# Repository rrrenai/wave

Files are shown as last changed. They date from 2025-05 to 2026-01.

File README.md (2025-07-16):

# ~ wave ~
*wave* is an attempt to revolutionize the head phone listening experience. If you know me irl, you'll know that I easily lose focus when people talk to me and I proactively believe I am going deaf. *wave* attempts to fix this issue by serving a a directional source selector for incoming sounds, eliminating distractions from environmental noise. 

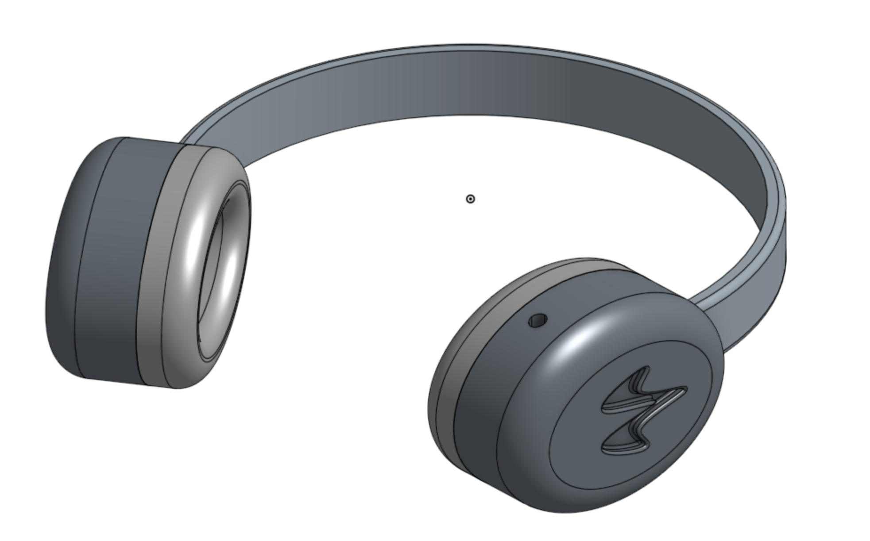
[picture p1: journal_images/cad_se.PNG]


These headphones utilize an FPGA, I2S MEMS microphones, and scrap headphone drivers. The FPGA and RPI work in tandem to collect and process incoming signals real time, seamlessly upgrading the listening experience.

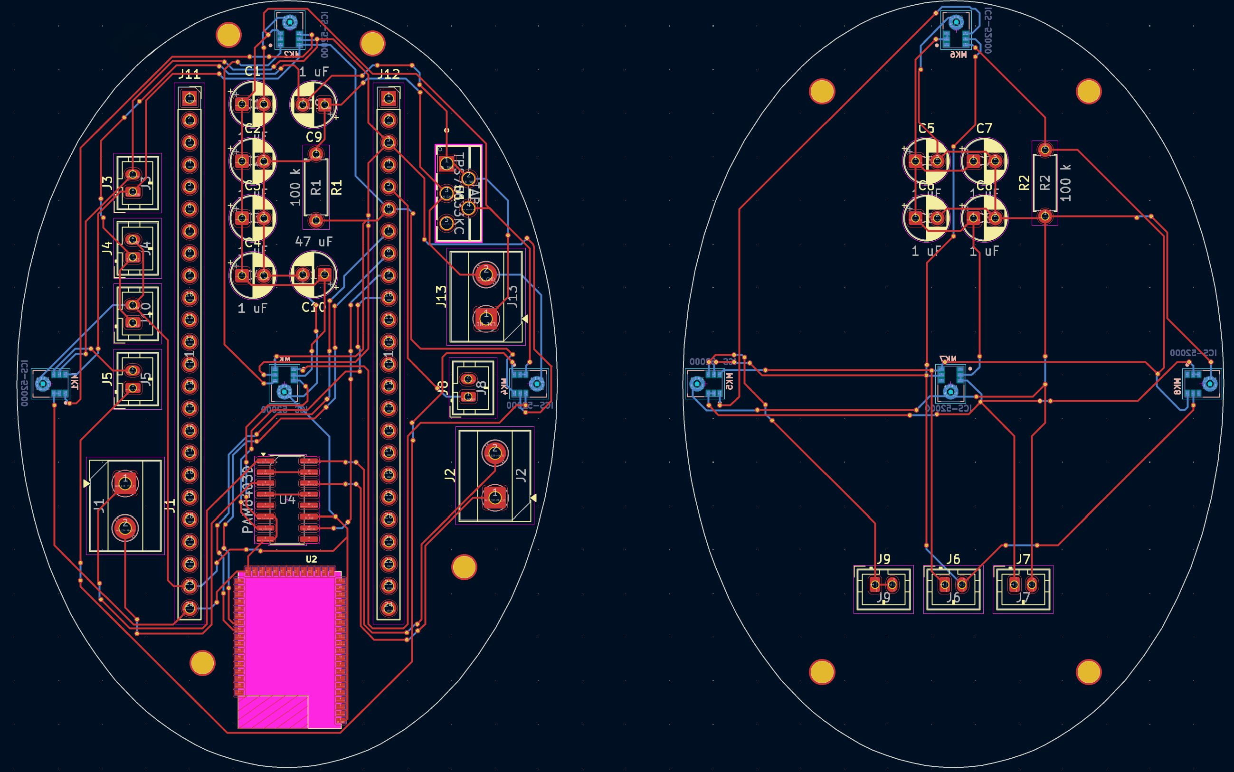
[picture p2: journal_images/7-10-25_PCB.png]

The headphones have 2 half PCBs, which are connected via 3 JST cables. It collects audio data through 8 ICS-520000 MEMS microphones, connected together via TDM and parsed directly on the FPGA. The data is then quickly ran through a reduced TF-Gridnet DNN, where the target speaker is isolated and played back to the user.

# Schematic
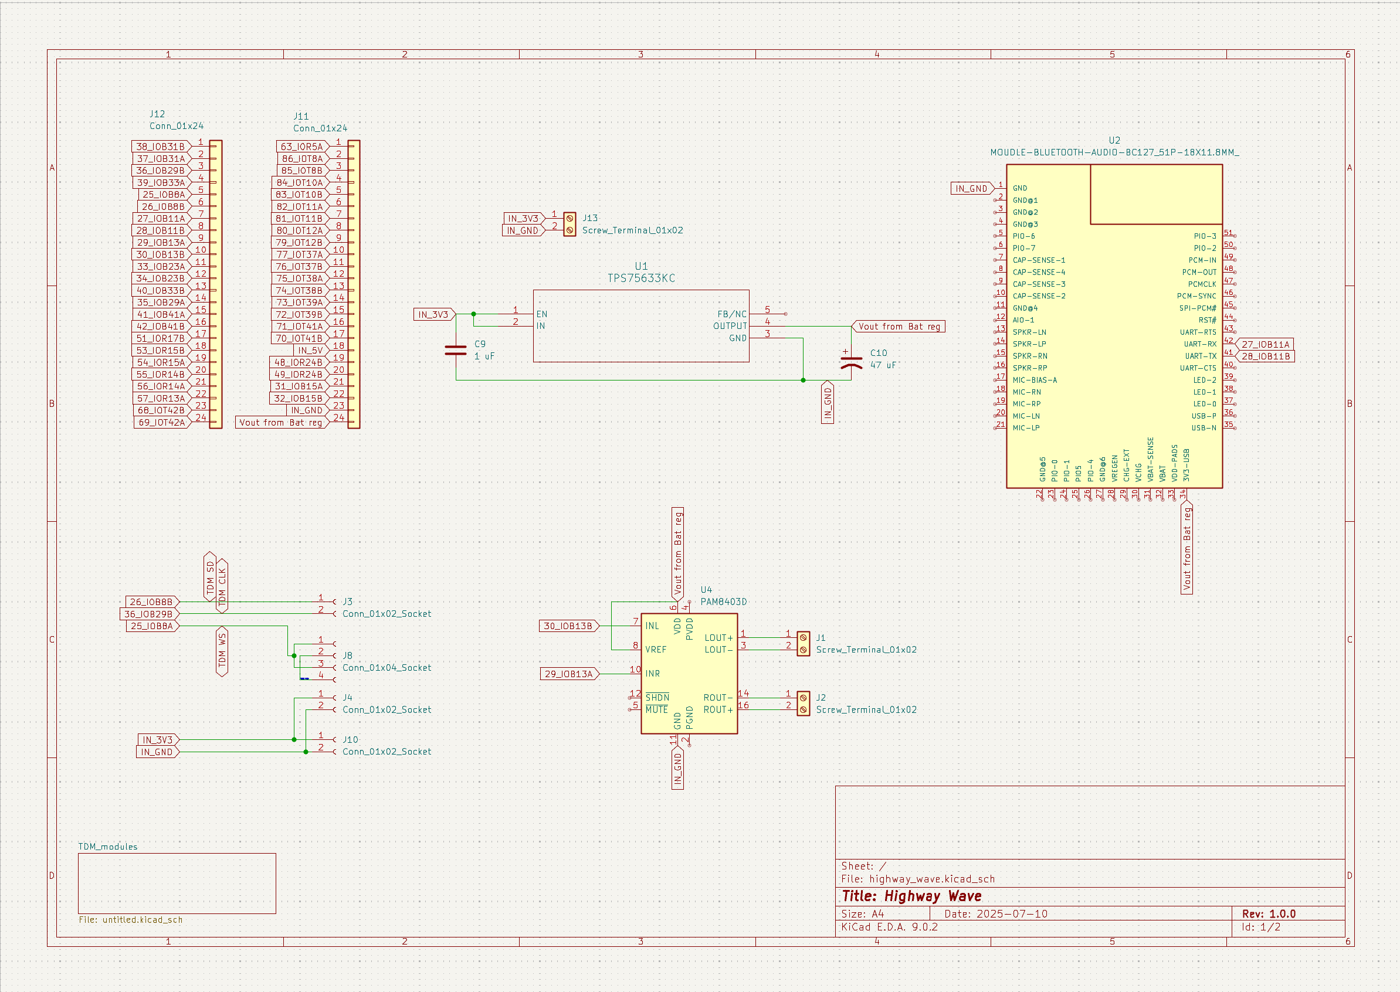
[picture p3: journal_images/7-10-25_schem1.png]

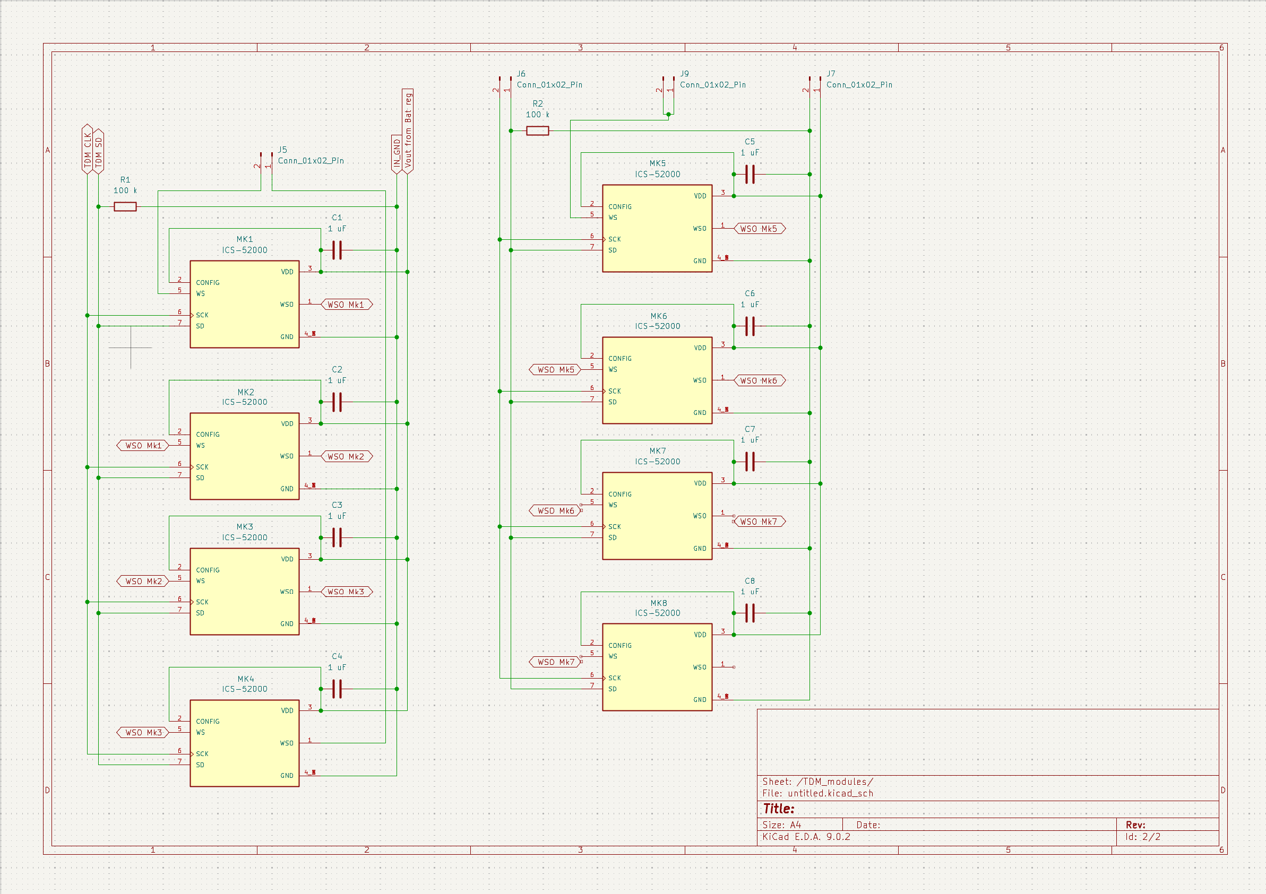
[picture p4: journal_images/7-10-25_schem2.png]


# BOM
| Item | Price | Quantity |  Subtotal |
|---|---|---|---|
| Ear cup / case |  $ 10.00 | 1 |  $ 10.00 |
| Head band |  $ 10.00 | 1 |  $ 10.00 |
| Bluetooth |  $ 1.79  | 1 |  $ 1.79 |
| Aliexpress shipping |  $ 6.63 | 1 |  $ 6.63 |
| Aliexpress tax |  $ 4.42 | 1 |  $ 4.42 |
| Cushion / seal material |  $ 5.26 | 2 |  $ 10.52 |
| LiPo |  $ 4.95 | 2 |  $ 9.90 |
| Sound amp |  $ 1.26 | 1 |  $ 1.26 |
| Charge Protection IC |  $ 1.99 | 1 |  $ 1.99 |
| Tang Nano 9k |  $ 18.17 | 1 |  $ 18.17 |
| Amazon Shipping / Handling  |  $ 12.98 | 1 |  $ 12.98 |
| Amazon Estimated Tax |  $ 9.11 | 1 |  $ 9.11 |
| Audio driver for headphones |  $ 10.69 | 2 |  $ 21.38 |
| Digikey Shipping |  $ 6.99 | 1 |  $ 6.99 |
| Digikey Tarriff |  $ 2.14 | 1 |  $ 2.14 |
| Ebay shipping |  $ 4.95 | 1 |  $ 4.95 |
| Ebay tax |  $ 0.64 | 1 |  $ 0.64 |
| Buttons |  $ 5.00  | 4 |  $ 20.00 |
| LED |  $ - | 2 |  $ - |
| PCB (L + R) |  $ 8.27 | 1 |  $ 8.27 |
| I2S Microphones |  $ 2.84 | 10 |  $ 28.40 |
| Mouser shipping |  $ 7.99 | 1 |  $ 7.99 |
| TOTAL | | |  $ 197.53 |

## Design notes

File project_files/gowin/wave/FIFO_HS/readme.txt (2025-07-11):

_______________________________________________________________________________
       	  FIFO_HS阅读指南
----------------------------------------------------------------------
工程描述：FIFO HS IP设计，并加载物理约束、时序约束、GAO配置等，实现整个设计流程。
----------------------------------------------------------------------
目标器件：GW1N-9C，GW1N-LV9LQ144C6/I5
----------------------------------------------------------------------
文件列表
----------------------------------------------------------------------
.
| -- project
|    `-- readme.txt			        -->	自述文件
|    `-- FIFO_HS.gprj			    -->	参考设计工程
|    |-- impl
|    |-- src
|        |-- FIFO_HS
|        |   |-- FIFO_HS.ipc		-->	IP配置文件
|        |   |-- FIFO_HS.v			-->	IP文件
|        |   |-- FIFO_HS.vo			-->	仿真使用vo文件
|        |   |-- FIFO_HS_tmp.v		-->	例化模板文件
|        |-- rstn_gen.v			    -->	工程文件
|        |-- test_fifo.v			-->	工程顶层文件
|        |-- FIFO_HS.cst  	 		-->	工程物理约束文件
|        |-- FIFO_HS.gpa  	 		-->	工程GPA配置文件
|        |-- FIFO_HS.sdc  	 		-->	工程时序约束文件
|        |-- FIFO_HS.rao			-->	工程GAO配置文件
|        |-- FIFO_HS.gvio			-->	工程GVIO配置文件

_______________________________________________________________________________
       	 FIFO_HS  Readme
----------------------------------------------------------------------
Project description：FIFO HS IP design, with physical constraints, timing constraints, Gao configuration file, etc. to realize the whole design process.
----------------------------------------------------------------------
Object device: GW1N-9C, GW1N-LV9LQ144C6/I5
----------------------------------------------------------------------
File List:
----------------------------------------------------------------------
.
| -- project
|    `-- readme.txt						-->	Read Me file (this file)
|    `-- FIFO_HS.gprj					-->	Gowin Project File for Example Design
|    |-- impl
|    |-- src
|        |-- FIFO_HS
|        |   |-- FIFO_HS.ipc			-->	IP configuration file	
|        |   |-- FIFO_HS.v			    -->	IP file	
|        |   |-- FIFO_HS.vo			    -->	Verilog simulation File for tb
|        |   |-- FIFO_HS_tmp.v		    -->	Template file for instantiation
|        |-- rstn_gen.v			        -->	File for Gowin Project
|        |-- test_fifo.v			    -->	File for Gowin Project
|        |-- FIFO_HS.cst  	 		    -->	CST File
|        |-- FIFO_HS.gpa  	 		    -->	GPA File
|        |-- FIFO_HS.sdc  	 		    -->	SDC File
|        |-- FIFO_HS.rao			    -->	GAO File
|        |-- FIFO_HS.gvio			    -->	GVIO File

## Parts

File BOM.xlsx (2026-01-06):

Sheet: Final
Item | Received | Purpose | Part Name | Supplier | Source | Alternative | Price | Quantity | Subtotal
Ear cup / case |  | Comfort | Printing on print Legion + shipping cost | #print-legion |  |  | $10.00 |  | $0.00
Head band |  | Comfort |  | #print-legion |  |  | $10.00 |  | $0.00
Bluetooth |  |  | Bluetooth 5.0 Audio Receiver | Aliexpress | https://www.aliexpress.us/item/3256805886601588.html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 |  | $1.79 | 1 | $1.79
Aliexpress shipping |  |  |  | Aliexpress |  |  | $6.63 | 1 | $6.63
Aliexpress tax |  |  |  | Aliexpress |  |  | $4.42 | 1 | $4.42
Cushion / seal material | 2025-08-16 | Comfort |  | Aliexpress | https://www.aliexpress.us/item/3256806614332934.html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 |  | $5.26 | 2 | $10.52
LiPo | 2025-08-28 |  | LP603449 | Aliexpress | https://www.aliexpress.us/item/3256808031709894.html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 |  | $4.95 | 2 | $9.90
Sound amp | 2025-08-16 | Boost sound / bass | PAM8403 | Aliexpress | https://www.aliexpress.us/item/3256807092800375.html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 |  | $1.26 | 1 | $1.26
Charge Protection IC | 2025-08-16 |  | TP4056 or TPS75633 | Aliexpress | https://www.aliexpress.us/item/3256803400457978.html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 |  | $1.99 | 1 | $1.99
Tang Nano 9k | 2025-08-16 | Process mics | GOWIN GW1NR-9 RISC-V | Amazon | https://www.aliexpress.us/item/3256804387309562.html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 |  | $18.17 | 1 | $18.17
Amazon Shipping / Handling |  |  |  | Amazon |  |  | $12.98 |  | $0.00
Amazon Estimated Tax |  |  |  | Amazon |  |  | $9.11 |  | $0.00
Audio driver for headphones |  | Play audio | HPD-50N25PR00-32 | Digikey | https://www.digikey.com/en/products/detail/peerless-by-tymphany/HPD-50N25PR00-32/6211129 | https://www.amazon.com/dp/B0B3S2CYZS?ref_=cm_sw_r_cp_ud_dp_47YHT647GW0YA5WC0RF3_1 | $10.69 | 2 | $21.38
Digikey Shipping |  |  |  | Digikey |  |  | $6.99 | 1 | $6.99
Digikey Tarriff |  |  |  | Digikey |  |  | $2.14 | 1 | $2.14
Ebay shipping |  |  |  | Ebay |  |  |  |  | $0.00
Ebay tax |  |  |  | Ebay |  |  | $0.64 | 1 | $0.64
Buttons |  | volume & bluetooth |  | Have |  |  | $5.00 | 4 | $20.00
LED |  | power indicator |  | Have |  |  | $0.00 | 2 | $0.00
PCB (L + R) |  |  |  | JCLPCB |  |  | $8.27 | 1 | $8.27
I2S Microphones | 2025-08-03 | Take audio input | ICS-5200 | Mouser | https://www.mouser.com/ProductDetail/TDK-InvenSense/ICS-52000?qs=u4fy%2FsgLU9PL4sQfWE4e7w%3D%3D | https://www.digikey.ca/en/products/detail/tdk-invensense/ICS-52000/6221214 | $2.84 | 10 | $28.40
Mouser shipping |  |  |  | Mouser |  |  | $7.99 | 1 | $7.99
1x24 female header | 2025-08-16 |  |  | Aliexpress | https://www.aliexpress.com/item/2251832818063874.html?mp=1 |  | $1.74 | 1 | $1.74
JST socket | 2025-08-16 |  |  | Aliexpress | https://www.aliexpress.com/item/3256806836296359.html?mp=1 |  | $3.14 | 1 | $3.14
JST Housing |  |  |  | Aliexpress | https://www.aliexpress.com/item/3256804769340392.html?mp=1 |  | $1.37 | 1 | $1.37
ceramic caps | 2025-08-16 |  |  | Aliexpress | https://www.aliexpress.com/item/3256807448788129.html?mp=1 |  | $4.97 | 1 | $4.97
pam8403 | 2025-08-16 |  |  | Aliexpress | https://www.aliexpress.com/item/3256808555282957.html?mp=1 |  | $1.33 | 2 | $2.66
screw terminal | 2025-08-16 |  |  | Aliexpress | https://www.aliexpress.com/item/3256803442947487.html?mp=1 |  | $4.45 | 1 | $4.45
desoldering braid | 2025-08-16 |  |  | Aliexpress | https://www.aliexpress.com/item/3256805212208632.html?mp=1 |  | $1.26 | 1 | $1.26 |  | estimate | actual
Total Price |  |  |  |  |  |  |  |  | $170.08 | Aliexpress | $76.77 | $84.09
 |  |  |  |  |  |  |  |  |  | Digikey | $30.51 | $31.02
 |  |  |  |  |  |  |  |  |  | Mouser | $36.39 | $39.70
 |  |  |  |  |  |  |  |  |  | PCB? | $8.27 | $1.63
 |  |  |  |  |  |  |  |  |  | TOTAL | $151.94 | $156.44

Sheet: Breakdown
Item | Price per unit | Quantity | Subtotal
Bluetooth 5.0 Audio Receiver | $0.18 | 1 | $0.18
Cushion / seal material | $5.26 | 1 | $5.26
LP603449 | $4.95 | 1 | $4.95
PAM8403 | $1.26 | 1 | $1.26
TPS75633 | $0.40 | 1 | $0.40
GOWIN Tang Nano 9k | $18.17 | 1 | $18.17
HPD-50N25PR00-32 | $10.69 | 2 | $21.38
PCB (L + R) | $8.27 | 1 | $8.27
ICS-5200 | $2.84 | 8 | $22.72
1x24 female header | $0.17 | 2 | $0.35
JST socket | $0.03 | 20 | $0.63
JST Housing | $0.01 | 20 | $0.27
ceramic caps | $0.02 | 8 | $0.13
screw terminal | $0.45 | 3 | $1.33
TOTAL |  |  | $85.31

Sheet: Copy of Final
Item | Purpose | Part Name | Source | Alternative | Price | Quantity | Subtotal
Audio driver for headphones | Play audio | HPD-50N25PR00-32 | https://www.digikey.com/en/products/detail/peerless-by-tymphany/HPD-50N25PR00-32/6211129 | https://www.amazon.com/dp/B0B3S2CYZS?ref_=cm_sw_r_cp_ud_dp_47YHT647GW0YA5WC0RF3_1 | $10.69 | 2 | $21.38 | Total Price | $305.15
Sound amp | Boost sound / bass | PAM8403 | https://www.amazon.com/PAM8403-Stereo-Amplifier-Control-Potentiometer/dp/B07N1268RY |  | $5.69 | 1 | $5.69
Raspberry Pi Zero 2 WH | Run ML (quad core 64 processing) |  |  |  | $15.00 | 1 | $15.00
Tang Nano 9k | Process mics | GOWIN GW1NR-9 RISC-V | https://a.co/d/abLnqeb |  | $23.25 | 1 | $23.25
I2S Microphones | Take audio input | INMP441 | https://www.aliexpress.us/item/3256807347494500.html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 |  | $8.00 | 16 | $128.00
Ear cup / case | Comfort |  |  |  | $10.00 | 2 | $20.00
Cushion / seal material | Comfort |  |  |  | $10.00 | 2 | $20.00
Head band | Comfort |  |  |  | $10.00 | 1 | $10.00
Battery | power | Lithium Polymer ion Battery | https://a.co/d/7bSCAC6 |  | $10.00 | 1 | $10.00
Buttons | volume & bluetooth |  |  |  | $5.00 | 4 | $20.00
Bluetooth |  | BC127 |  |  | $6.05 | 1 | $6.05
Charge Protection IC |  | TP4056 or TPS75633 | https://www.ebay.com/itm/2-5-10PCS-TP4056-5V-1A-USB-18650-Lithium-Battery-Charger-Board-Protection-Module/132530522140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 |  | $2.16 | 1 | $2.16
LiPo |  | LP603449 | https://a.co/d/85SM4hH |  | $23.62 | 1 | $23.62
LED | power indicator

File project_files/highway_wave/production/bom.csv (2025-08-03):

Designator | Footprint | Quantity | Value | LCSC Part #
C5, C6, C7, C8 | C_Disc_D5.0mm_W2.5mm_P5.00mm | 4 | 1 uF
J10, J4, J6 | JST_PH_B2B-PH-K_1x02_P2.00mm_Vertical | 3 | Conn_01x02_Pin
J21 | TerminalBlock_MetzConnect_Type101_RT01602HBWC_1x02_P5.08mm_Horizontal | 1 | Screw_Terminal_01x02
J24 | JST_PH_B2B-PH-K_1x02_P2.00mm_Vertical | 1 | Conn_01x02_Socket
MK5, MK6, MK7, MK8 | MIC_ICS-52000 | 4 | ICS-52000
R2 | R_Axial_DIN0207_L6.3mm_D2.5mm_P7.62mm_Horizontal | 1 | 100 k

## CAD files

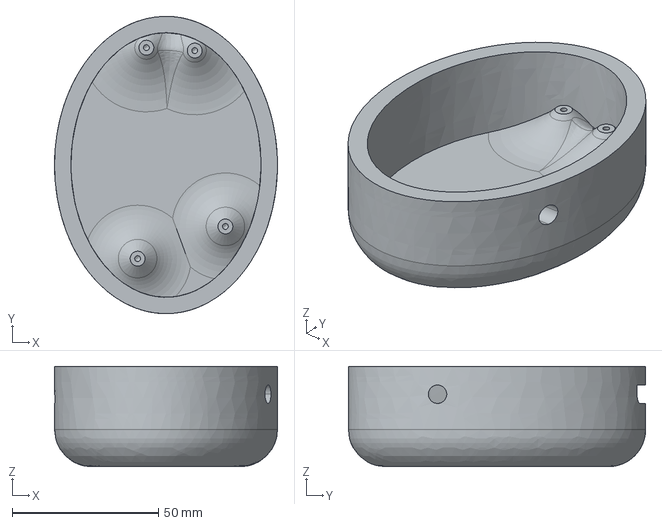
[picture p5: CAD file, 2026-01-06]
extra production/Ear_cup_L.step
76.2 x 101.6 x 34.3 mm

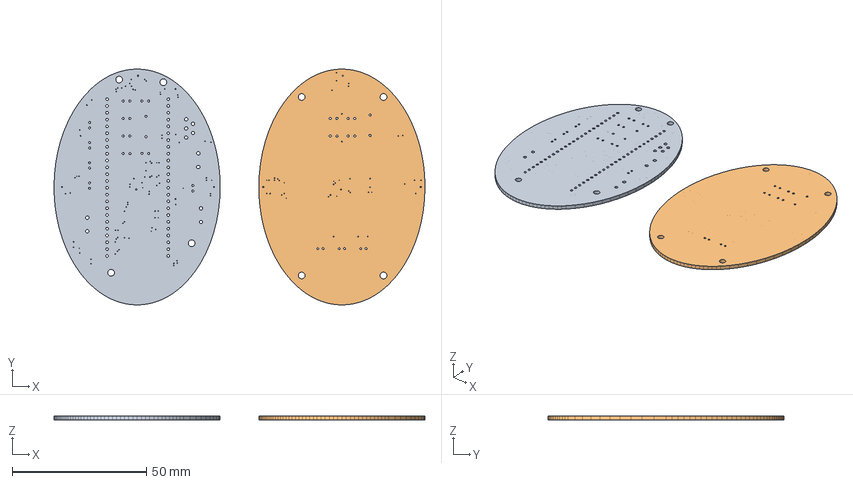
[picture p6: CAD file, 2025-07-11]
project_files/highway_wave/highway_wave.step
138.2 x 87.8 x 1.51 mm
highway_wave_PCB_1
highway_wave_PCB_2

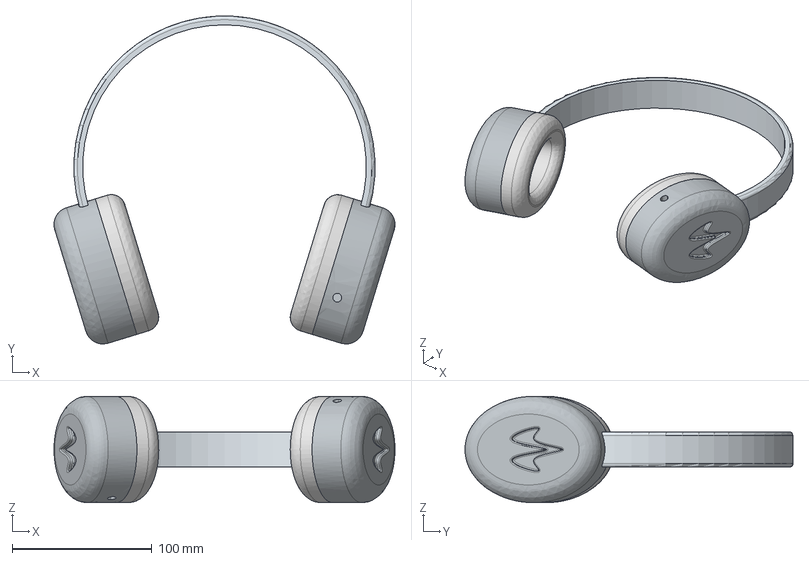
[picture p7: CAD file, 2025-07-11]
project_files/onshape/highway_wave.step
244.3 x 235.0 x 76.2 mm
Ear cup RIGHT
highway_wave_PCB_1
Ear pad x 2
Ear cup LEFT
head band
highway_wave_PCB_2

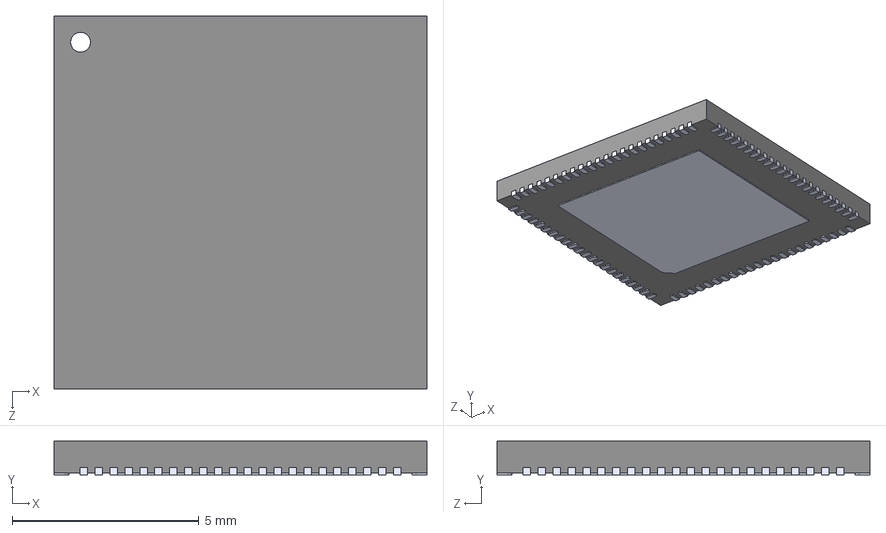
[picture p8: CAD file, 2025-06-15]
project_files/snapeda/GW1N-LV9QN88C6_I5_/GW1N-LV9QN88C6_I5_.step
10.0 x 0.9 x 10.0 mm

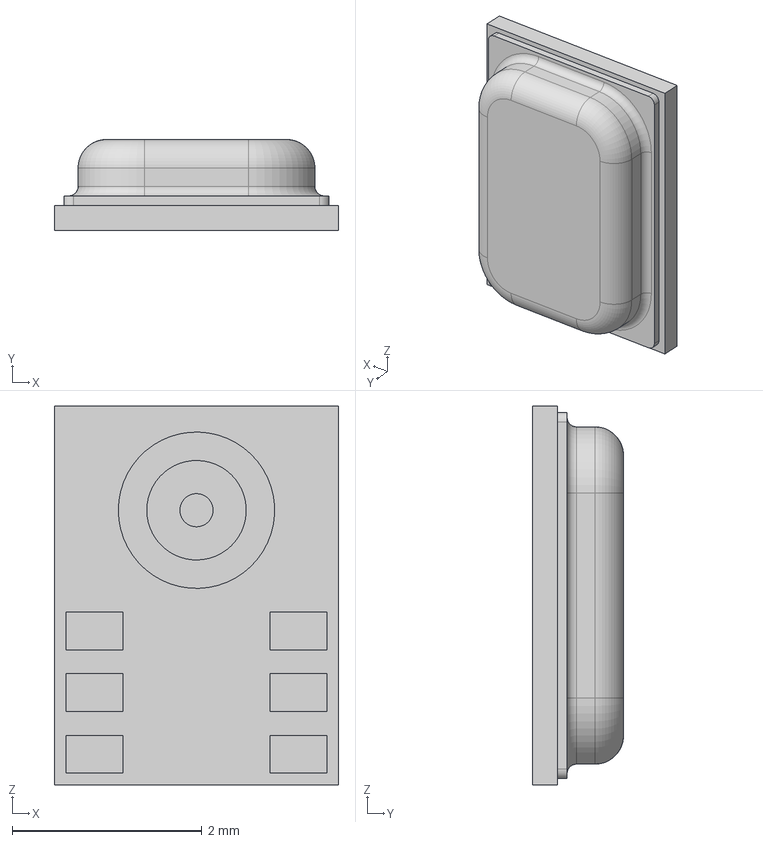
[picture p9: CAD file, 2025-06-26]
project_files/snapeda/ICS-43432/ICS-43432.step
3.00 x 0.961 x 4.00 mm

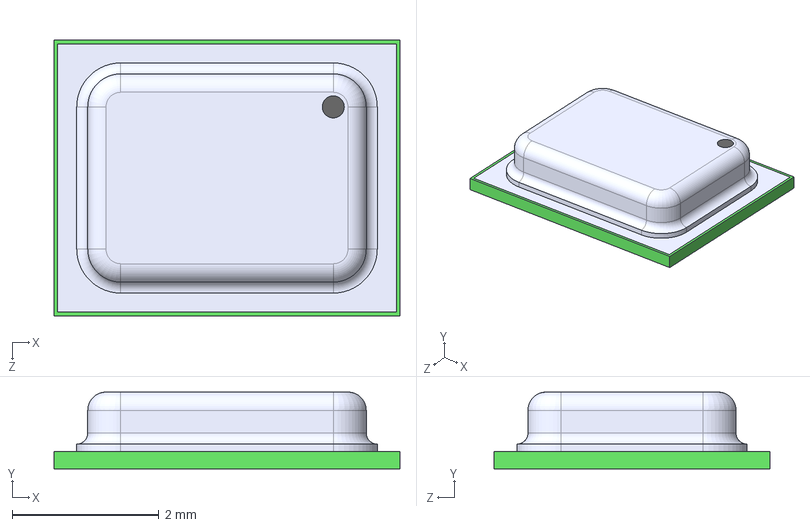
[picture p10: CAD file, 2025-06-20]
project_files/snapeda/INMP441ACEZ-R7/INMP441ACEZ-R7.step
4.72 x 1.05 x 3.76 mm

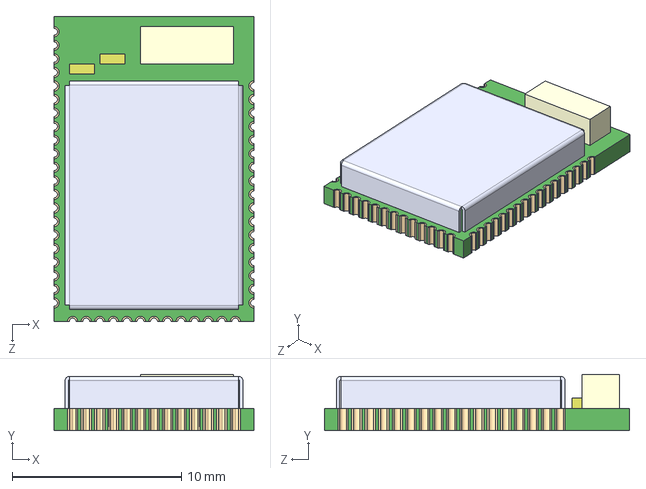
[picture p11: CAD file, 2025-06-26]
project_files/snapeda/MOUDLE-BLUETOOTH-AUDIO-BC127_51P-18X11.8MM_/MOUDLE-BLUETOOTH-AUDIO-BC127_51P-18X11.8MM_.step
11.8 x 3.32 x 18.0 mm

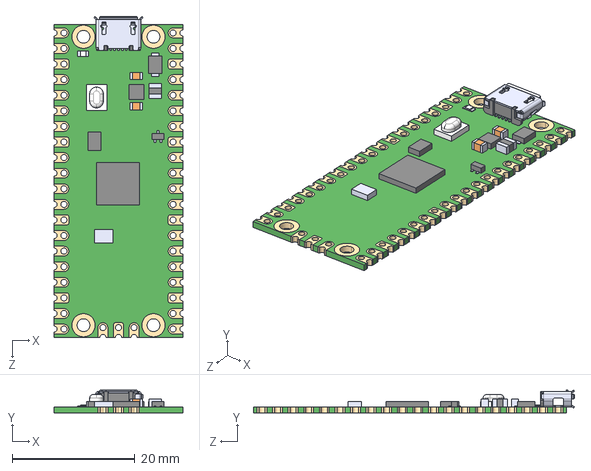
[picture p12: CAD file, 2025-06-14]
project_files/snapeda/RASPBERRY_PI_PICO/RASPBERRY_PI_PICO.step
21.0 x 3.73 x 52.3 mm

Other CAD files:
project_files/snapeda/ICS-52000/ICS-52000.step
extra production/Ear_cup_R.step

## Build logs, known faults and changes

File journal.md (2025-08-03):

---
title: "~ wave ~"
author: "rrrenai"
description: "Directional headphones to assist in multi-speaker selection"
created_at: "2024-05-22"
---
# Total time spent: 34.5
(Likely will increase after I get the parts cuz FPGAs are kind of a nightmare)

# May 22nd: Starting!

Hello, today I started writing my project pitch. I created my BOM and look at some other projects for inspiration.

Here's what I have so far:
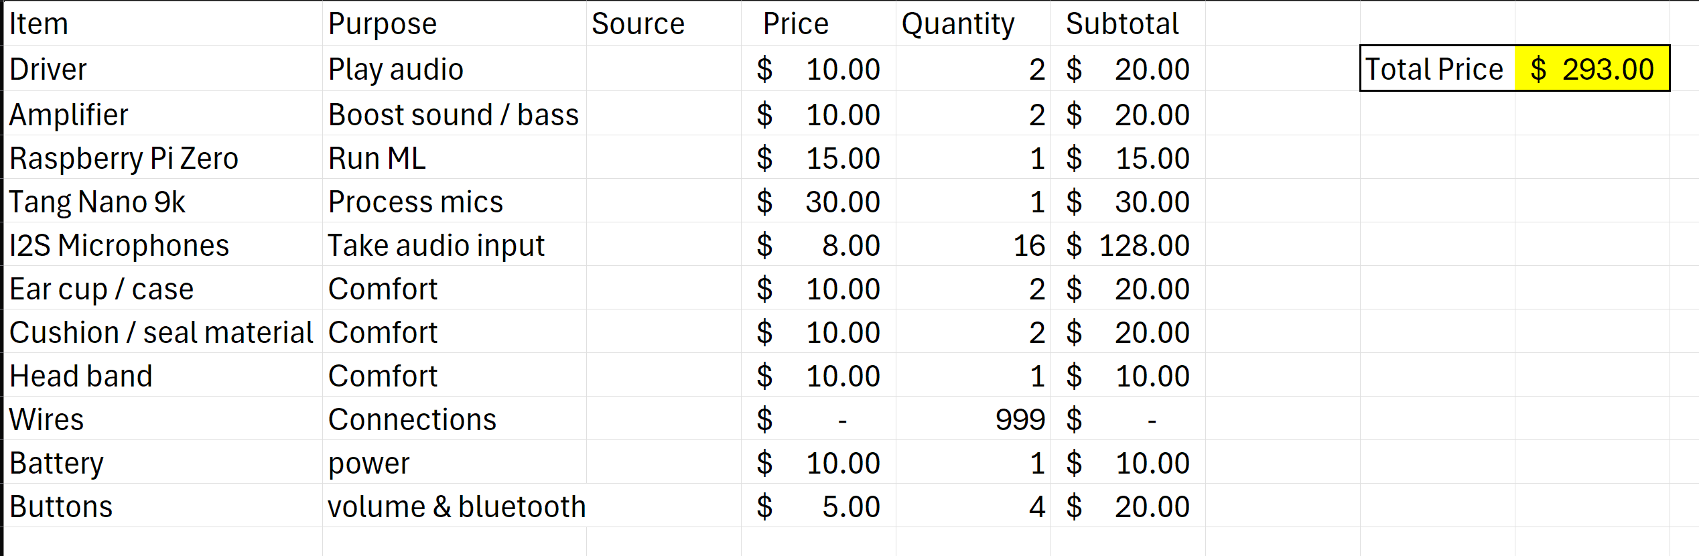
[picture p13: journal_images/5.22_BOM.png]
5/22/2025 BOM


I want to create something that can listen to omnidirectional audio and significantly clean up the output. I hope to help people with hearing problems.

**Time spent: 1 h**

---
# June 13th: Finished the headphone CAD

Today I used OnShape to design the electronic housing + headband.

The Tang Nano 9k is the largest item I anticipate using and thus I designed the ear cup around it. Here's a picture for the size of the Tang Nano 9k:
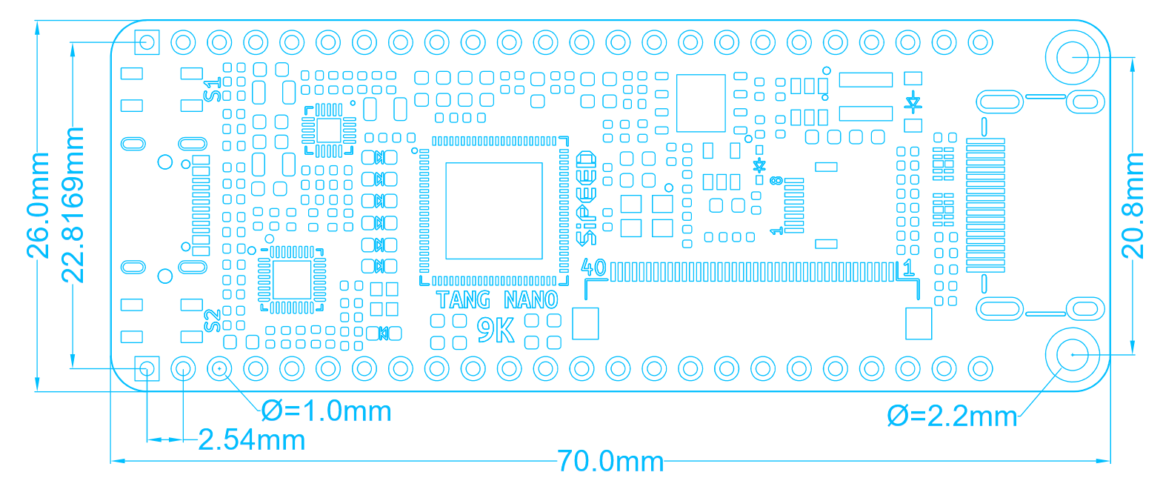
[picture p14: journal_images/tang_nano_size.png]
Tang Nano 9K


Here's what the headphones look like. I like the logo!
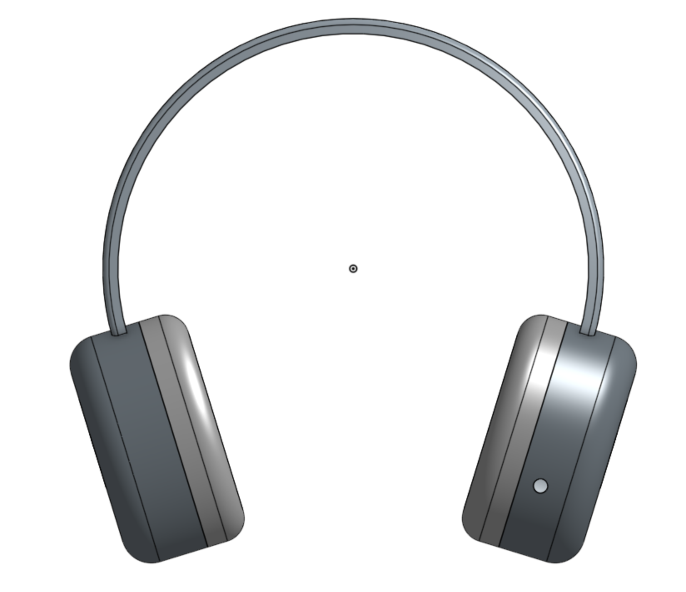
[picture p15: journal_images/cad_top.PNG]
top

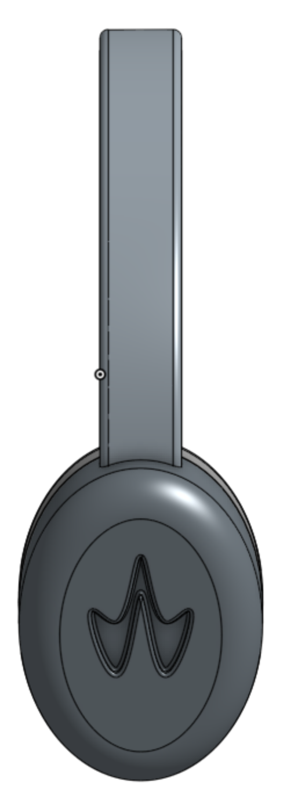
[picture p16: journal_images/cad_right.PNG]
side

southeast

Also, I started the schematic. I imported the Raspberry Pi Zero W onto the schematic and tried finding the footprint for the Tang Nano 9k but I wasn't able to :/ Guess I'll continue tmr? 

**Time spent: 4.5 h**

---
# June 14th: Continued working on Schem

There isn't any existing footprint for the Tang Nano 9k so I figured the Gowin chip it uses would be a sufficient representation of the board. Here's what the schem looks like so far::
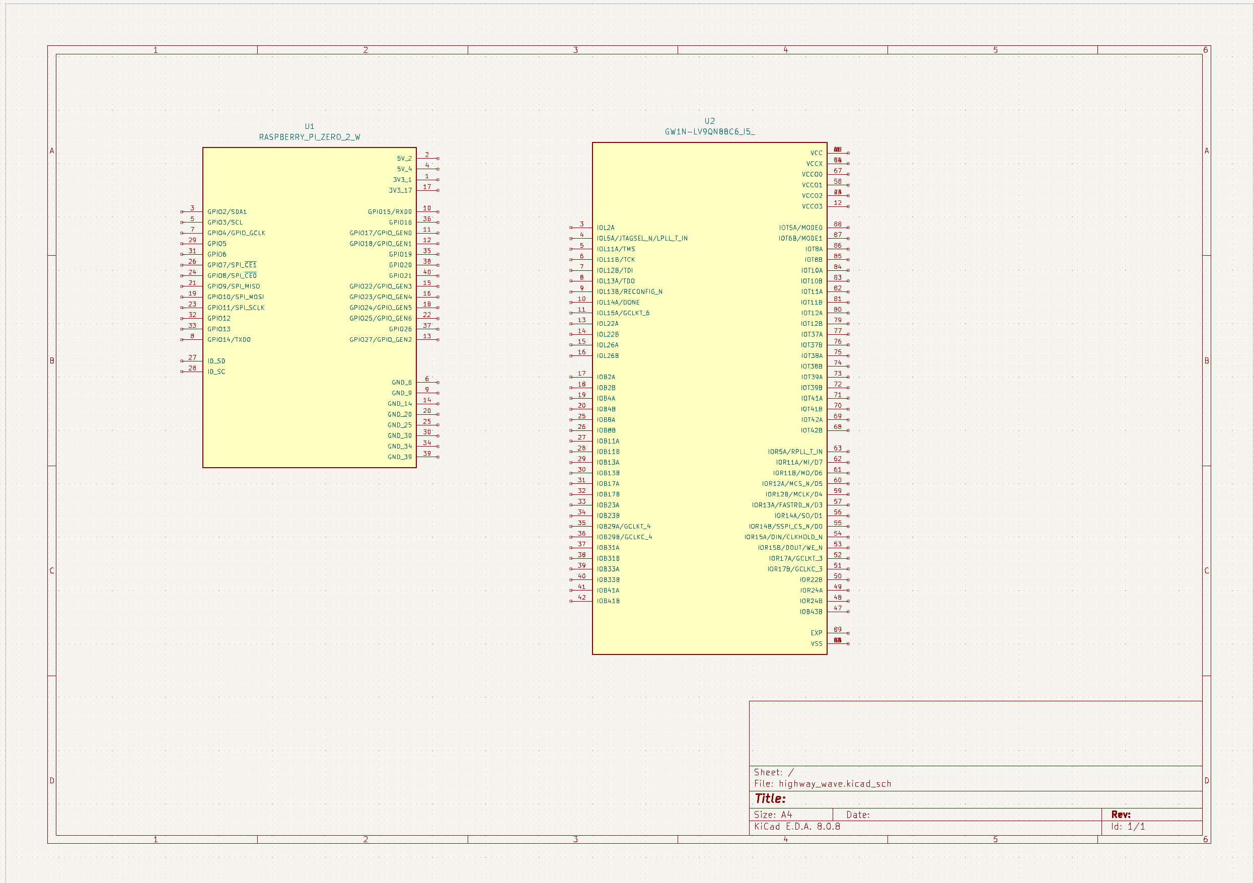
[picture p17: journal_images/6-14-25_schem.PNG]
Schem on 6/14/25


I also did research on the most appropriate driver for my application. Here are some quick facts:
Dynamic (Most common)
- Electromagnet causes voice coil to vibrate for sound waves
- What does resistance have to do with the quality?

Planar magnetic
- Need amp

Balanced armature
- Small build for in-=ear monitors
- Pivot between two magnets to make sound

Electrostatic
- Static charge applied to thin film between two pieces of metal
- Free from secondary distortion
- Expensive compared to others

Piezoelectoric
- Voltage applied to crystal or ceramic

Bone-Conduction
- Vibrate bones
- Sound leakage

I think dynamic drivers are the best for me since I want to focus more on the software aspect rather than experiment with driver quality. Dynamic drivers are well established and have tons of documentation. However, I still need to figure out which model to buy...

**Time spent: 1.5 h**

---
# June 19th: FINISHED Schem

OH MY GOD THIS TOOK ALL DAY. 
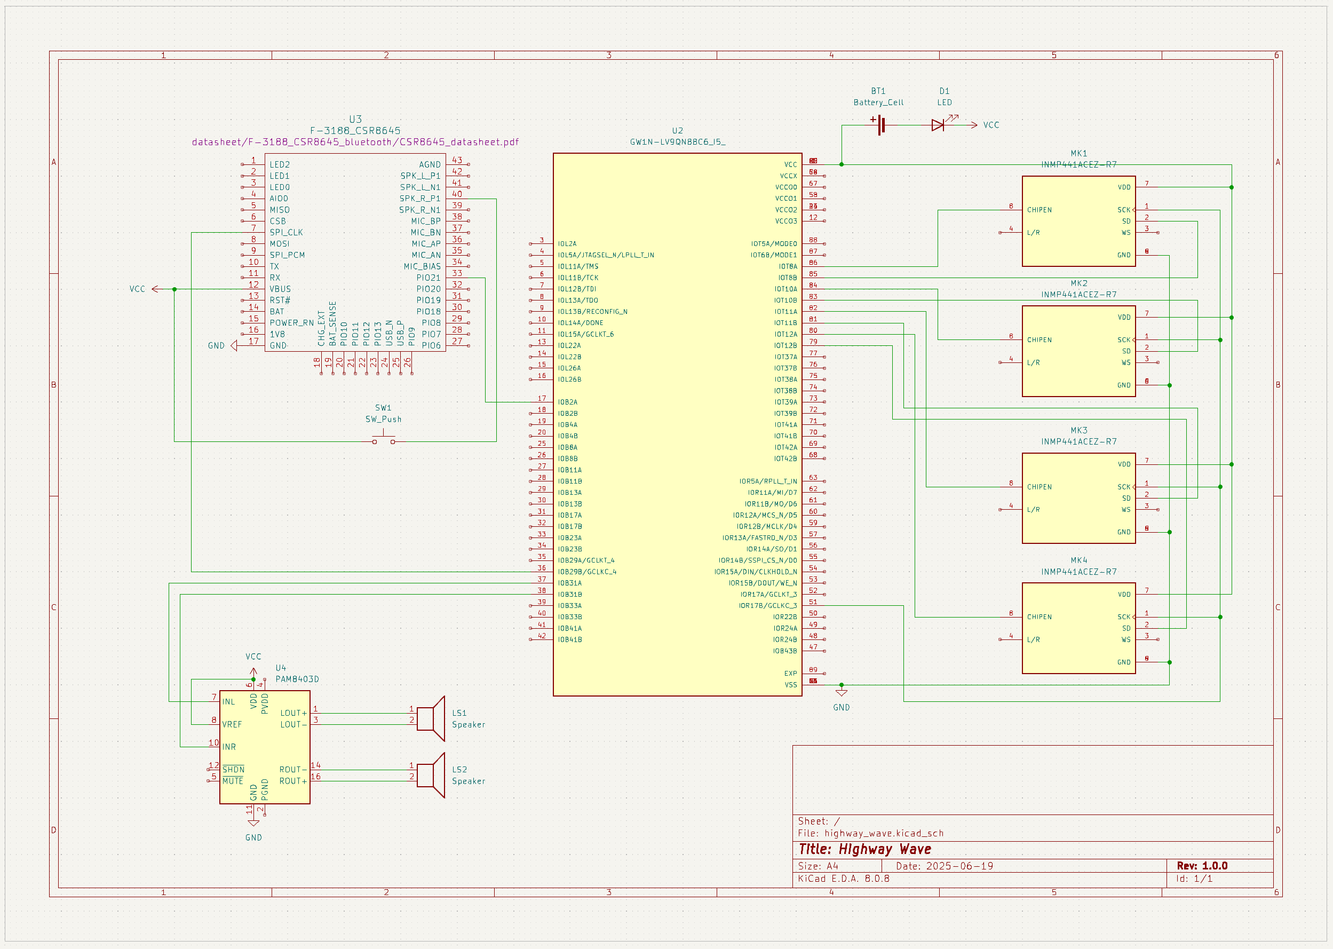
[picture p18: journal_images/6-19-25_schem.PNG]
schem


I updated the BOM with the component names and found footprints for all essential items. This in itself took maybe 2 hours to finish especially because I was a little indecisive and sometimes the footprint was just pay-walled :/

Anyway, after I finished finding all the kicad.sch files, I looked up datasheets an added it to the "reference_files" folder. I used these datasheets in figuring out how to wire these items. 

My BOM requests 16 I2S mics but I only wired 4 on the schem to conserve space. All of them would be wired in the same way and do essentially the same operation. 

There's a bunch of software things I need to figure out once I get all the stuff so yea.

**Time spent: 3.5 h**

---
# June 22nd: Revised schem

My entry was rejected I think? But I needed to simplify it a bit anyway. 

I think I'm gonna move away from FPGA to make the project more feasible. Cool idea but idk how to implement it.

Here's the schematic as of now:
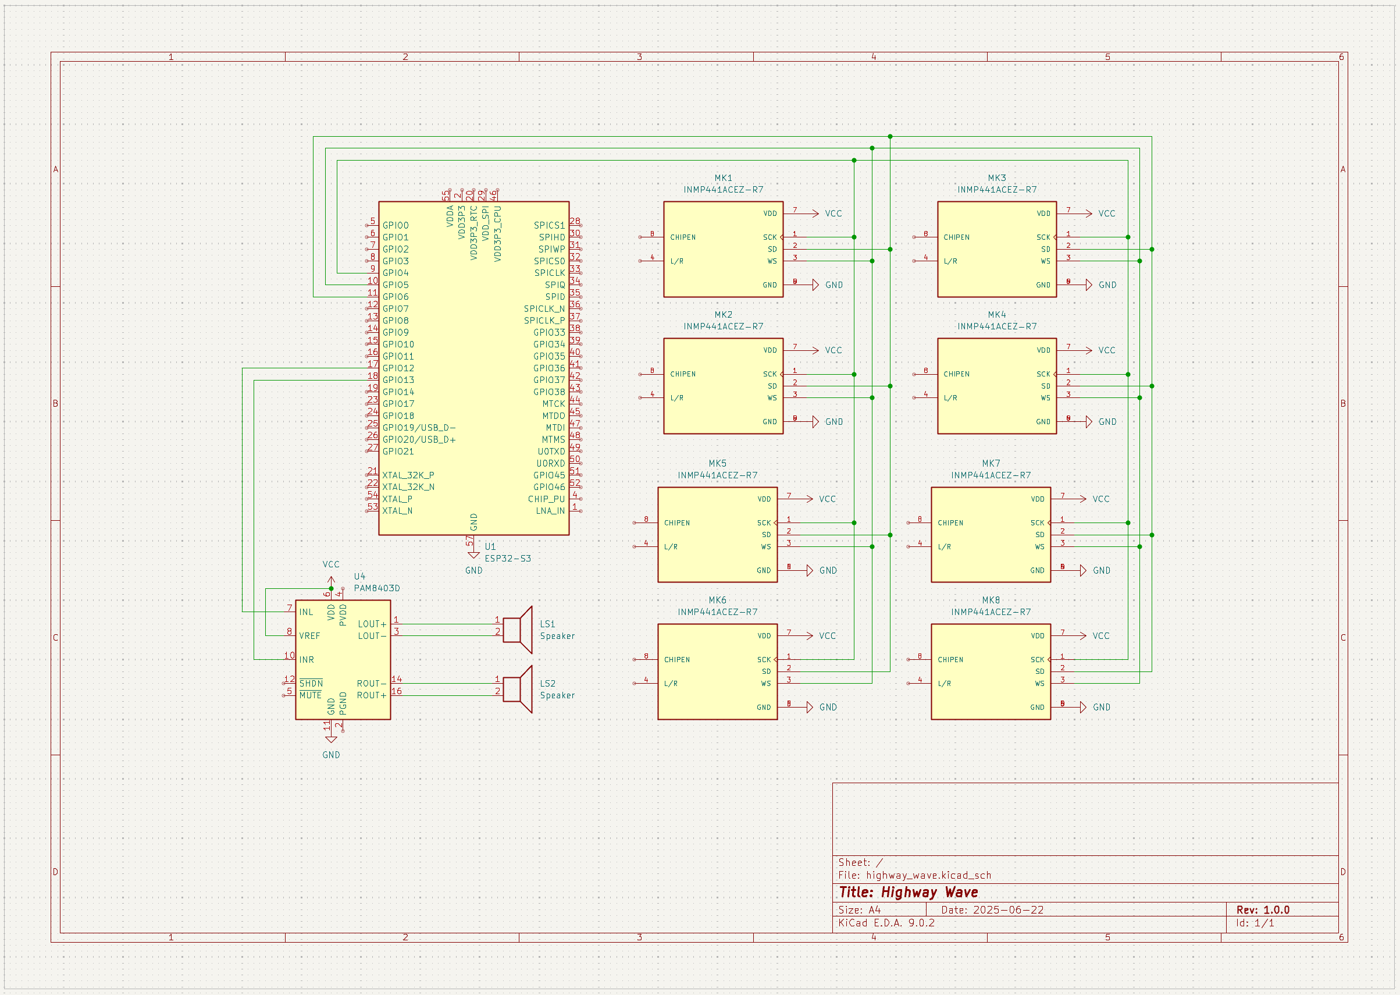
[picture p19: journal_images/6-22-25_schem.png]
schem


I reverted back to an ESP32-S3 cuz that's what I'm familiar with. Plus, it has TDM support so I can get low latency audio using I2S mics. Most of the time spent today was just on researching appropriate approaches to this project.

**Time spent: 3.5 h**

---
# June 25th: Re-re-direction back to FPGA

Ok I just thought a lot about what my project means to me and I think a lot of it is just learning more and I'd like to do that with an FPGA. I have a better idea of how I'm gonna approach this project and refined some of the things I'm including.

MAJOR change: using a TDM mic array
* INMP441 didn't have a good footprint so I looked around and found the ICS 43434 which I thought did what I wanted but I found that wiring TDM is better (time dimensional multiplexing)
* ok THUS I shifted to using ICS 52000
* also new BLE module cuz I couldnt for the life of me find the footprint for the one I chose initially (prob cuz I just took whatever was on ebay)

Schems as of today: 
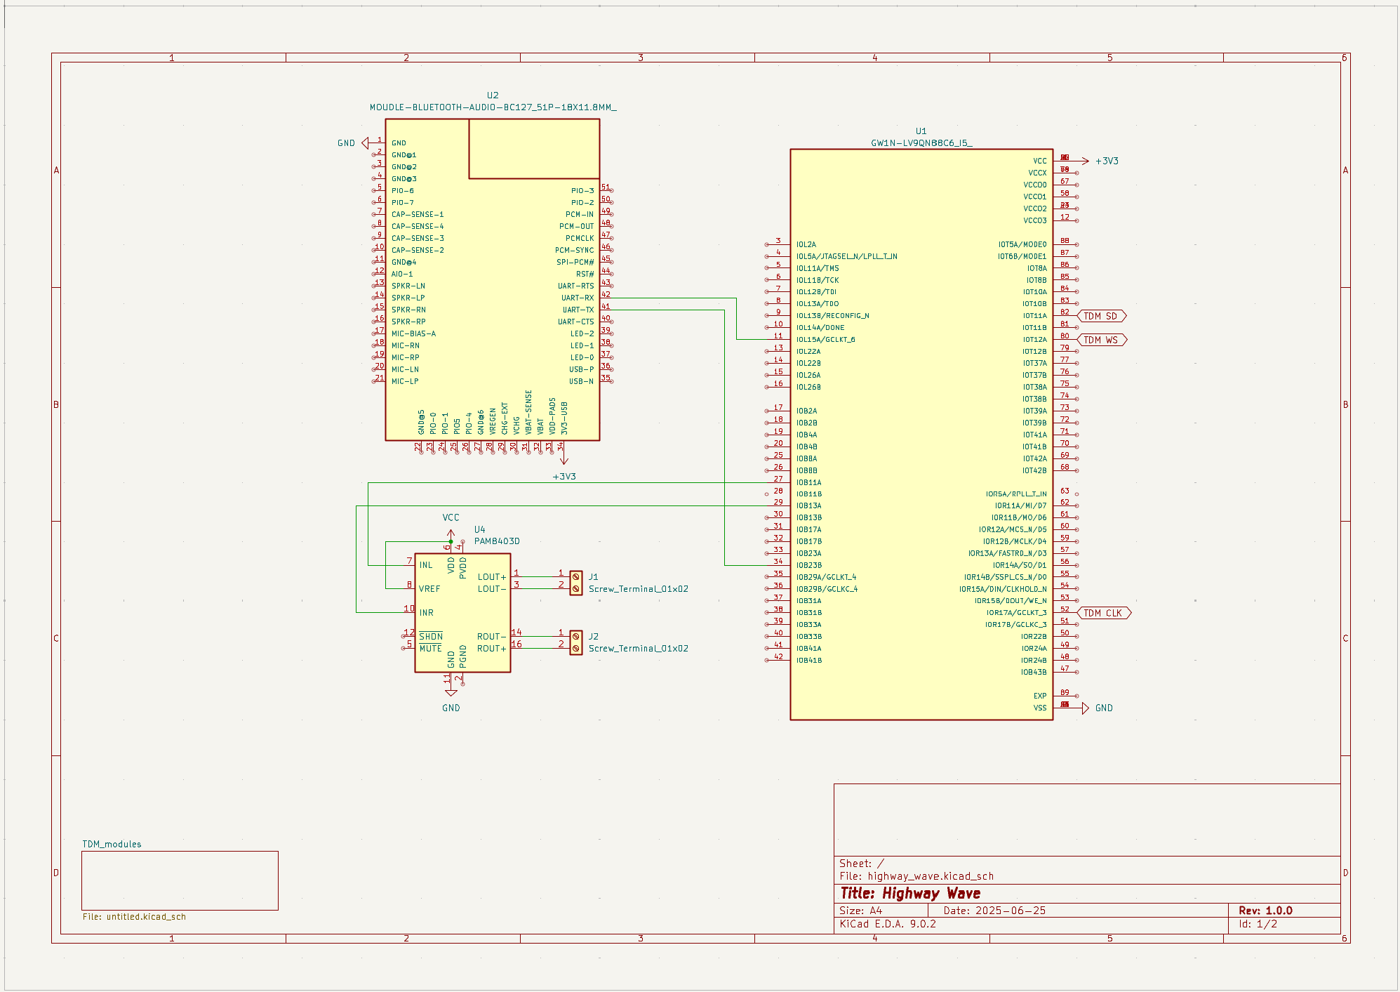
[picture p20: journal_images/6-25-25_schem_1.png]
first page

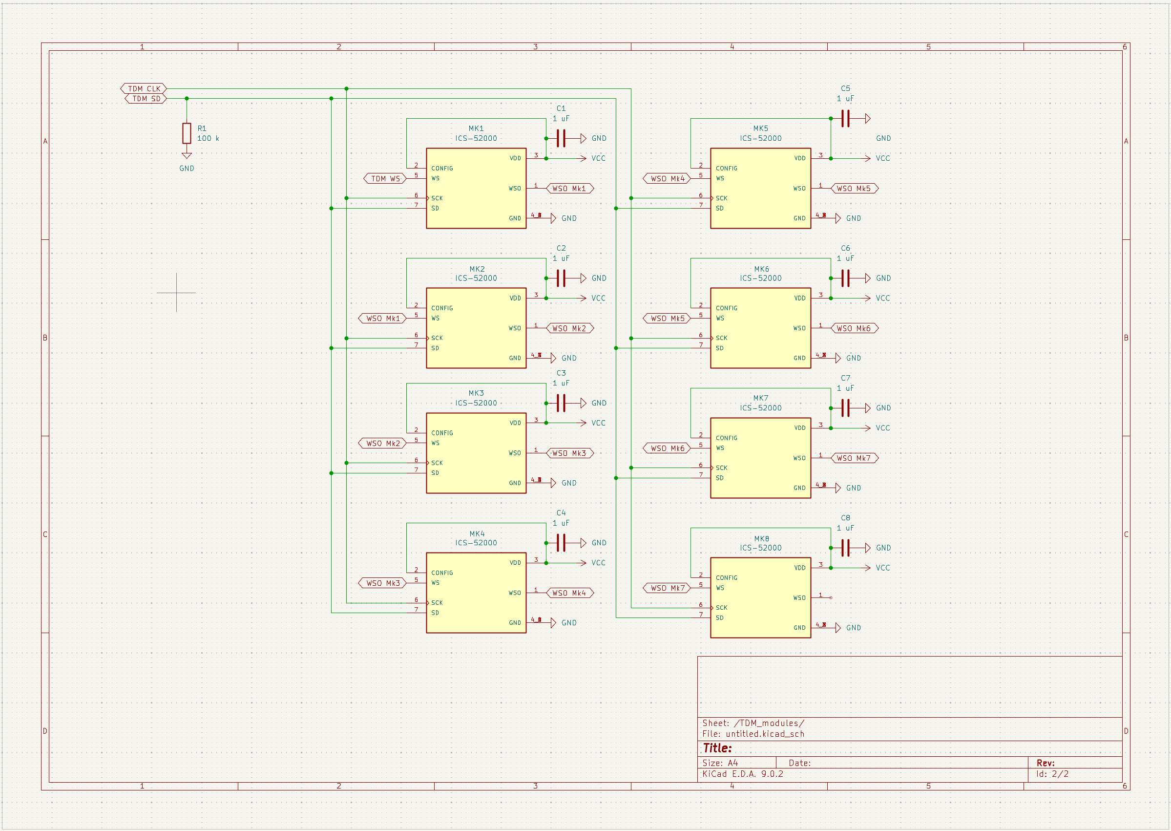
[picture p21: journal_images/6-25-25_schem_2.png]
second page

* I learned abt hierarchical schems today!!

**Time spent: 5 h**

---
# July 2/3/4 Redoing all PCB and fitting it into Onshape

Ngl I completely forgot to do journals. But I did redo the entire pcb, added tap holes, made an actual ovalar edge cut using a vector, and crashed tfo when I discovered it was still too big :)

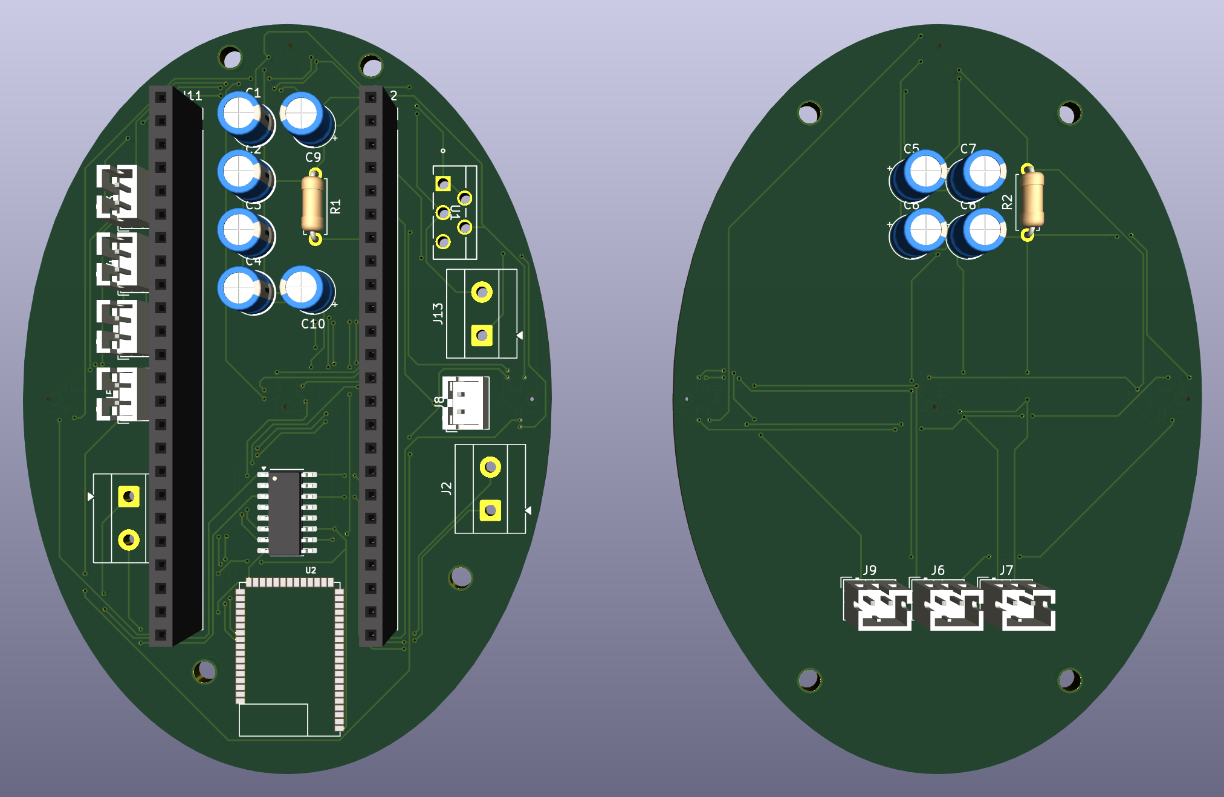
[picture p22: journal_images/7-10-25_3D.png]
3D Front

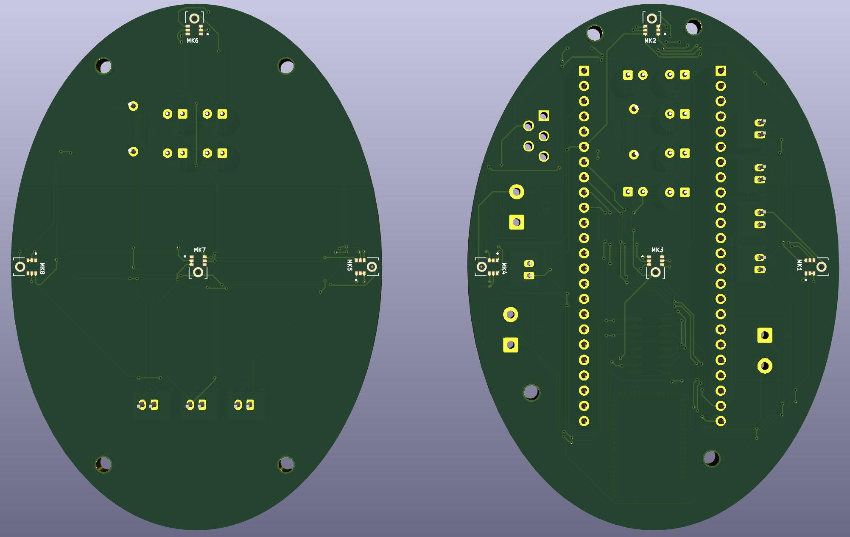
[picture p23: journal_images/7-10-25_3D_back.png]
3D Back

PCB
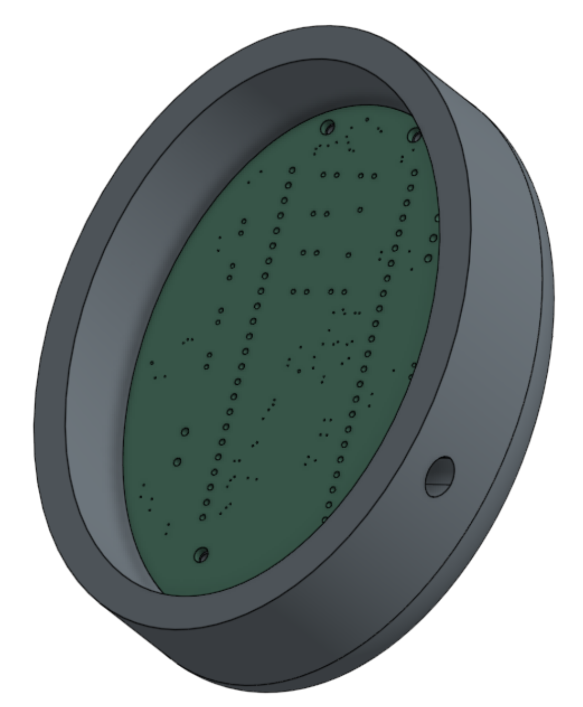
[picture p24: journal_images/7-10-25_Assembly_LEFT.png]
Assembly left


Oh yea also I changed the schem a lot so that I can order the Tang Nano 9k and just plug it in to my pcb.
schem 1
schem 2
I made a hierachical schem and broke out the ICS-52000 MEMS mics onto the second page. Each side of the PCB is connected with JST connectors, which will run via the head band and be hidden with a layer of cotton batting.

**Time spent: 10 h**

--- 
# July 10th: Finally wrapping this up and hopefully passing the grant!!!

Added my Verilog files from the GOWIN EDA app (top file found in `./project_files/gowin/wave/src/top.v`). I also touched up a little bit of the Onshape file, produced the gerber files, and will update the BOM in a bit.

**Time spent: 1 h**

--- 
#July 28th: Moved caps

I'm so done. This is like my fourth time submitting. Please PLEASE go thru.

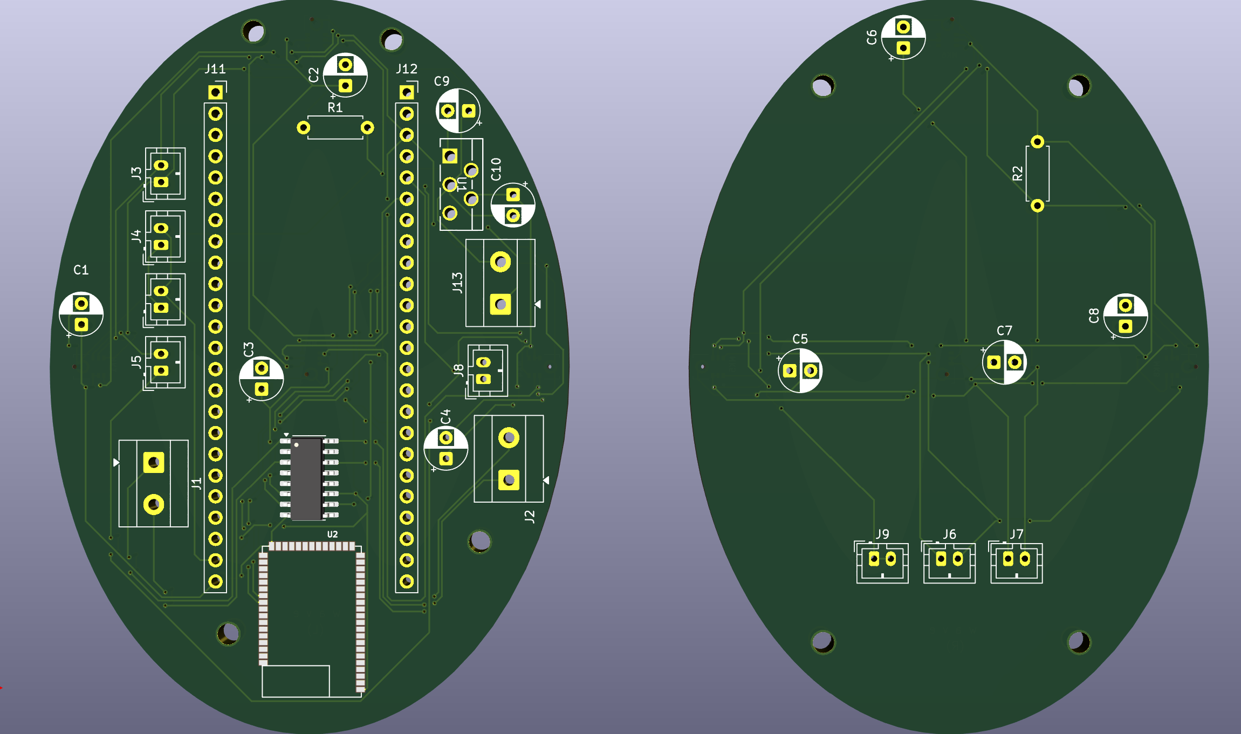
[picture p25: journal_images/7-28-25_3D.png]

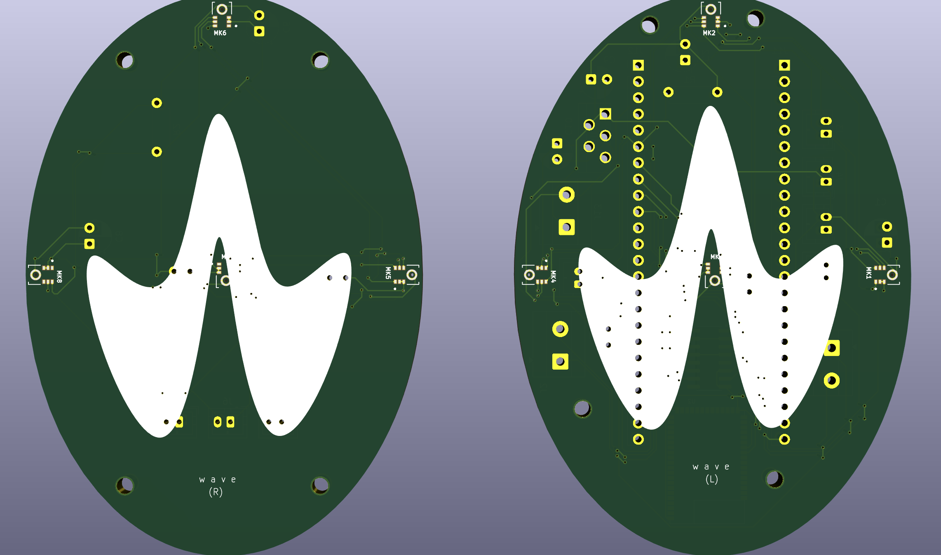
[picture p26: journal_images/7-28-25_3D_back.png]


**Time spent: 1 h**

---
#August 2nd: Ordering / Part Update

I ordered the Mouser / Digikey items. Need to re-review? cuz adding stuff to Aliexpress order.

**Time spent: 1 h**

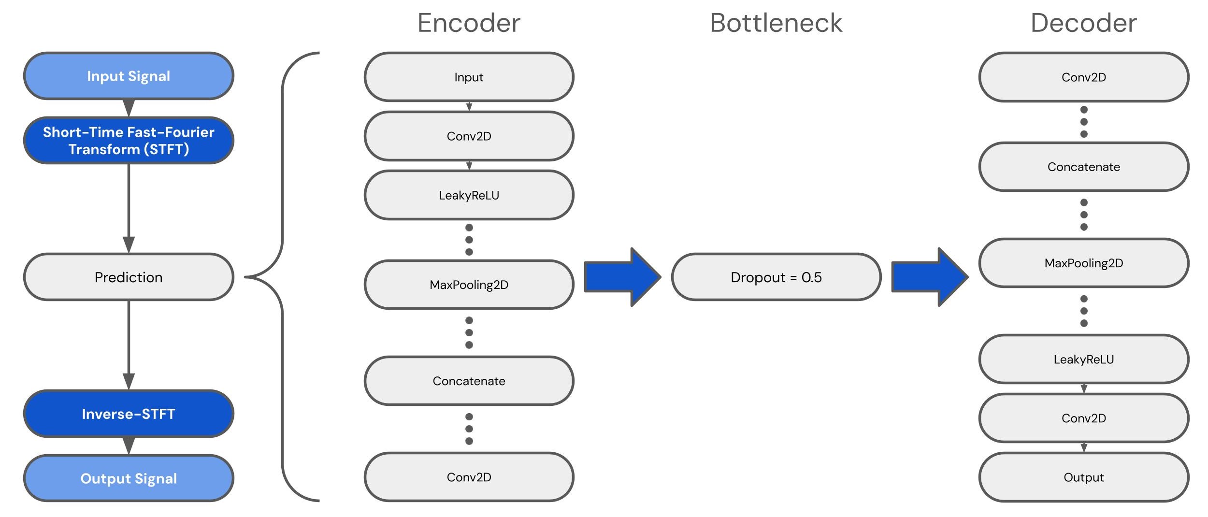
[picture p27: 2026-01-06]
journal_images/12-26-25_pipeline.jpg

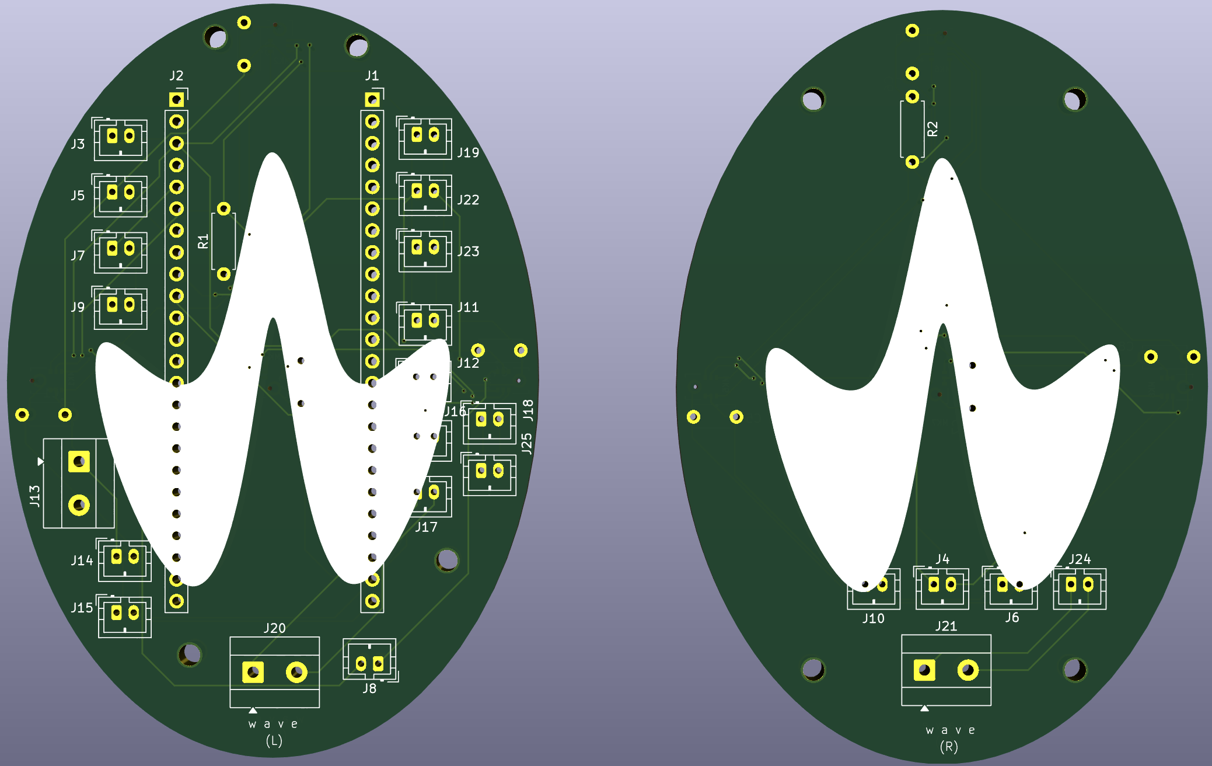
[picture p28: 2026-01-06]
journal_images/11-8-25_3d.png

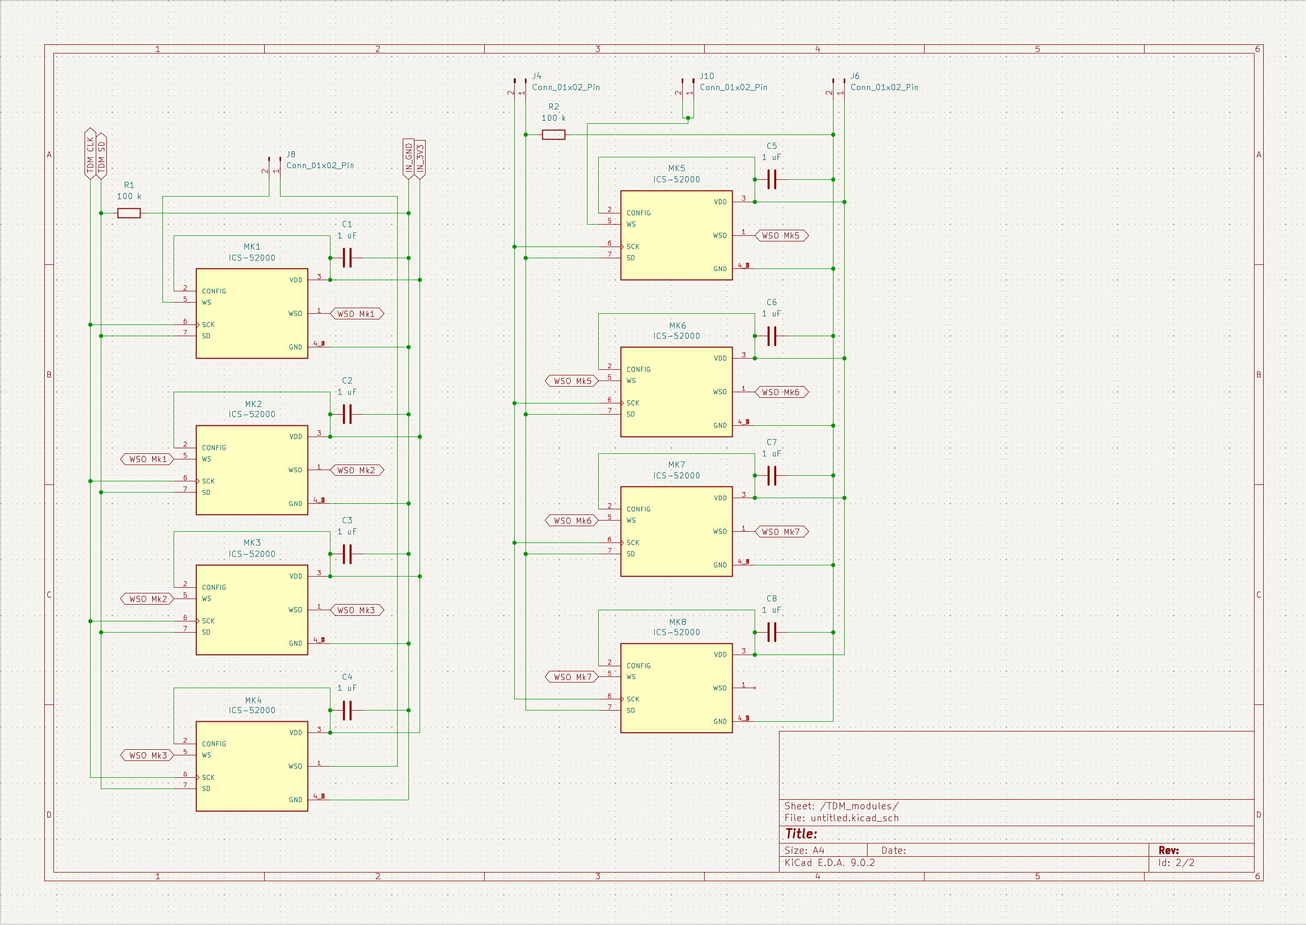
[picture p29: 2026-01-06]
journal_images/11-8-25_schem_2.png

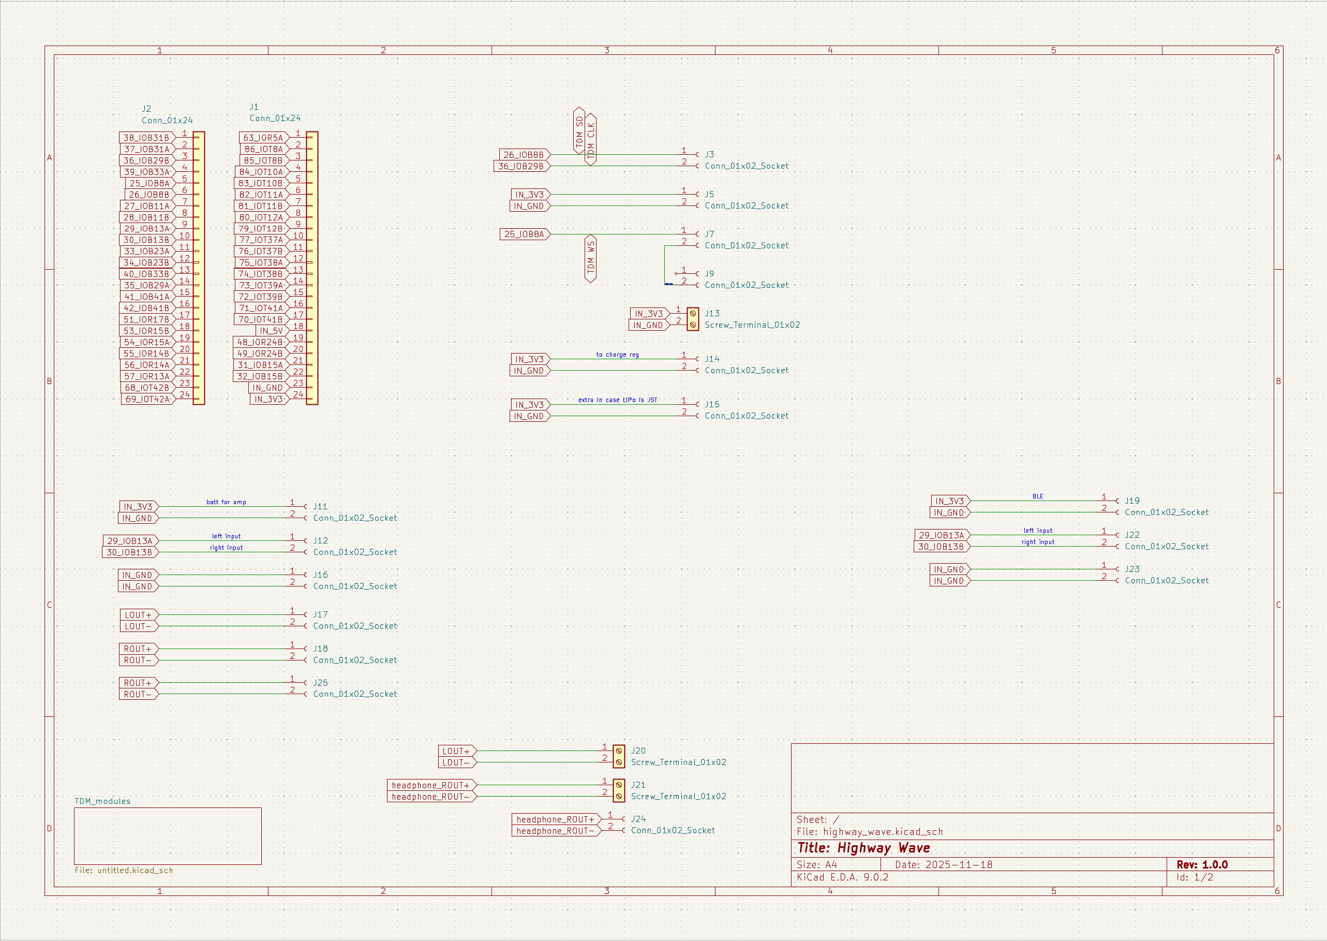
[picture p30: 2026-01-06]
journal_images/11-8-25_schem.png

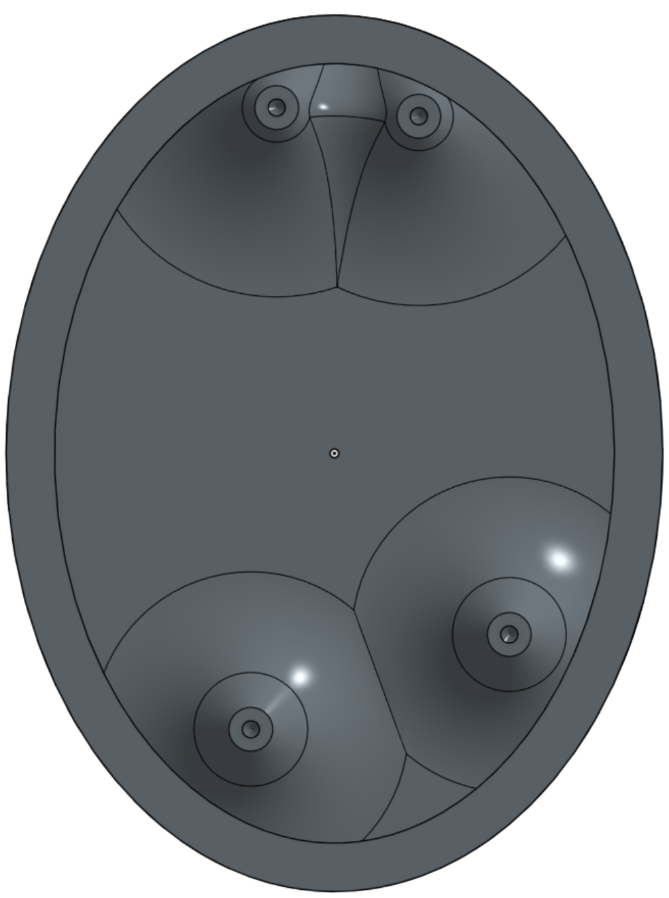
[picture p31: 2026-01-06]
journal_images/12-26-25_inner_LEFT.png

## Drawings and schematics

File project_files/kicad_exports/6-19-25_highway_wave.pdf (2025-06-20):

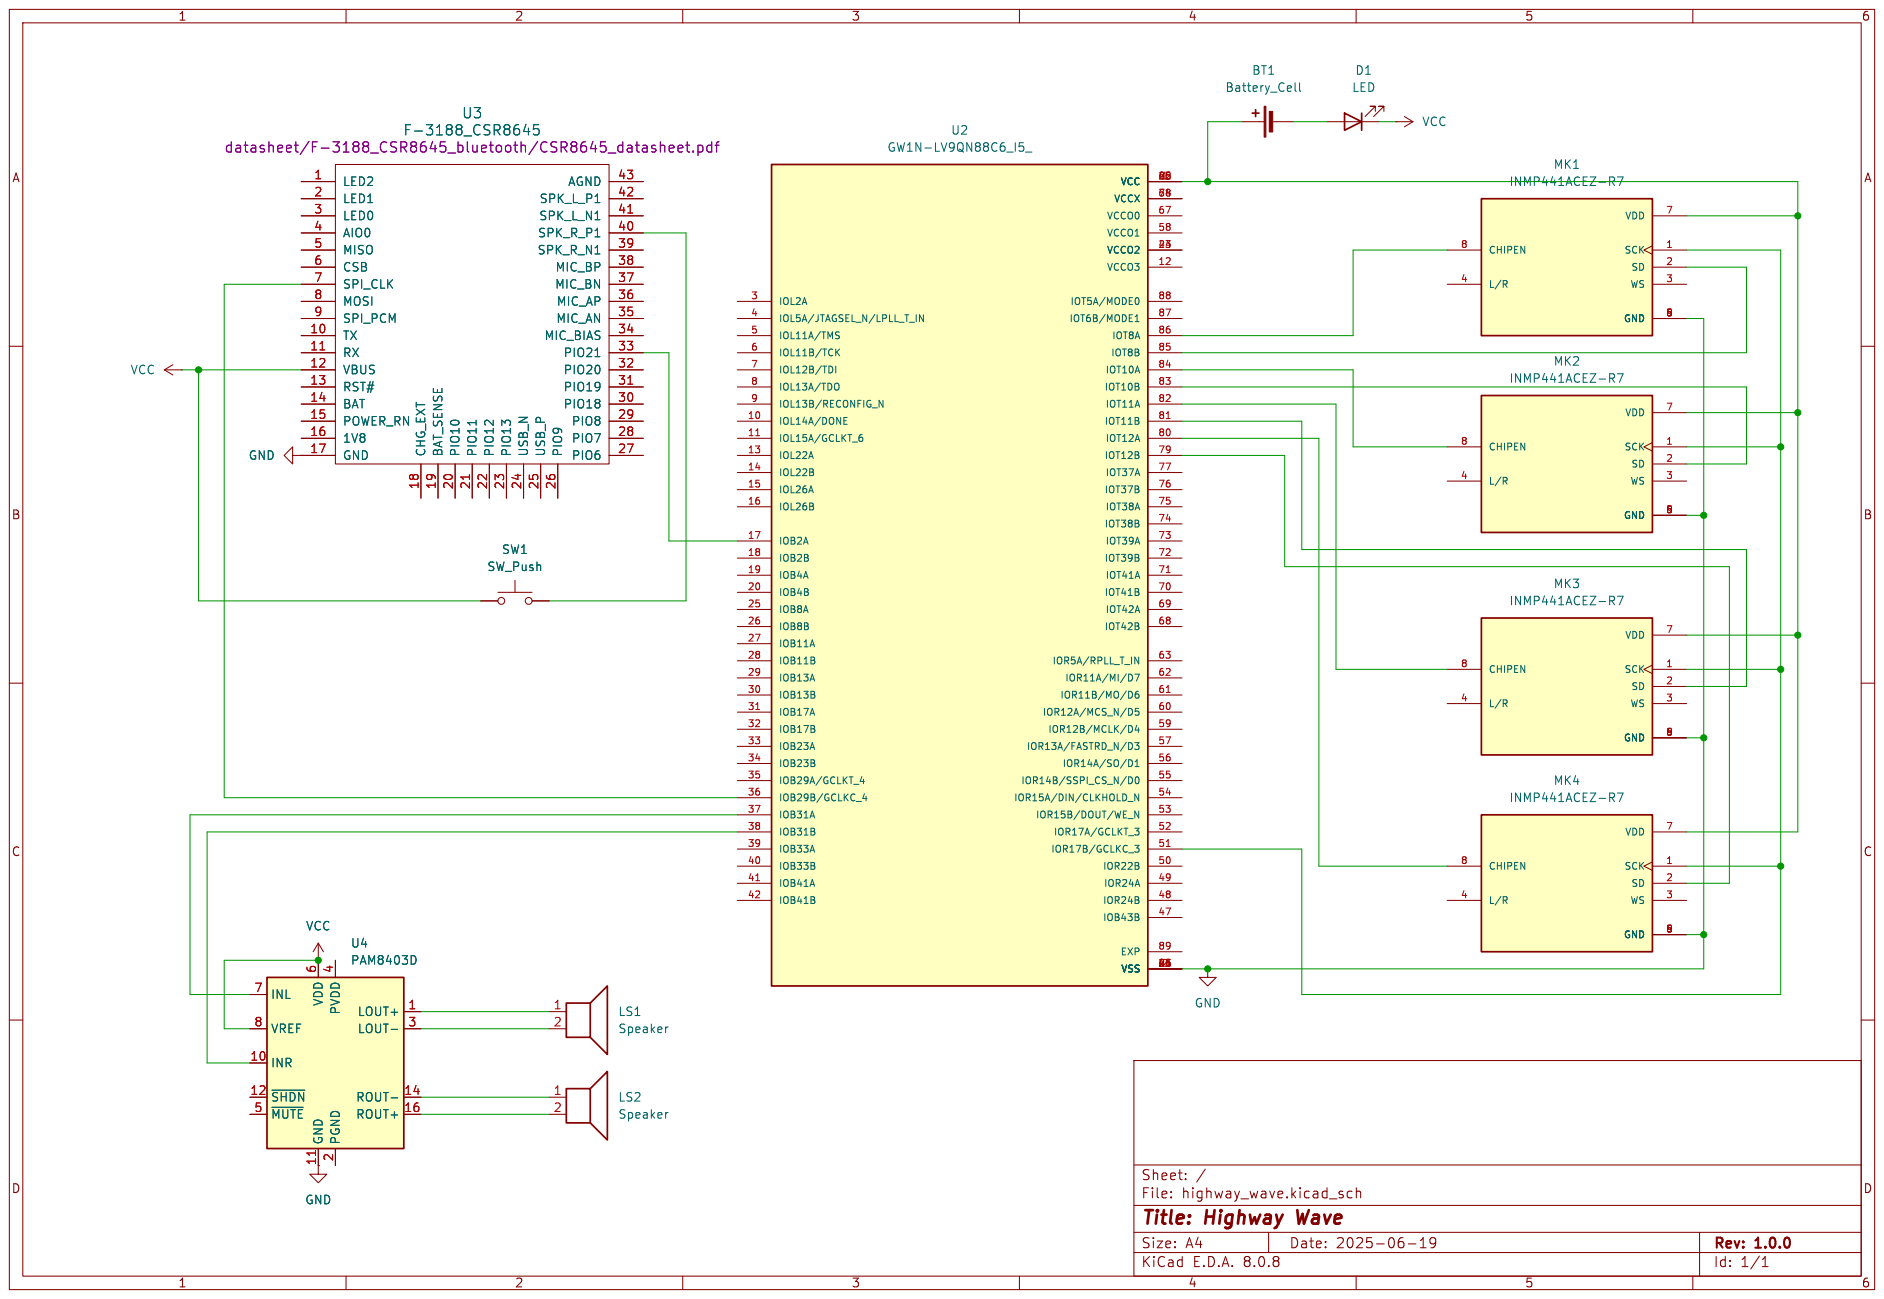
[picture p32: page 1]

File: highway_wave.kicad_sch Sheet: /
Id: 1/1 Title: Highway Wave

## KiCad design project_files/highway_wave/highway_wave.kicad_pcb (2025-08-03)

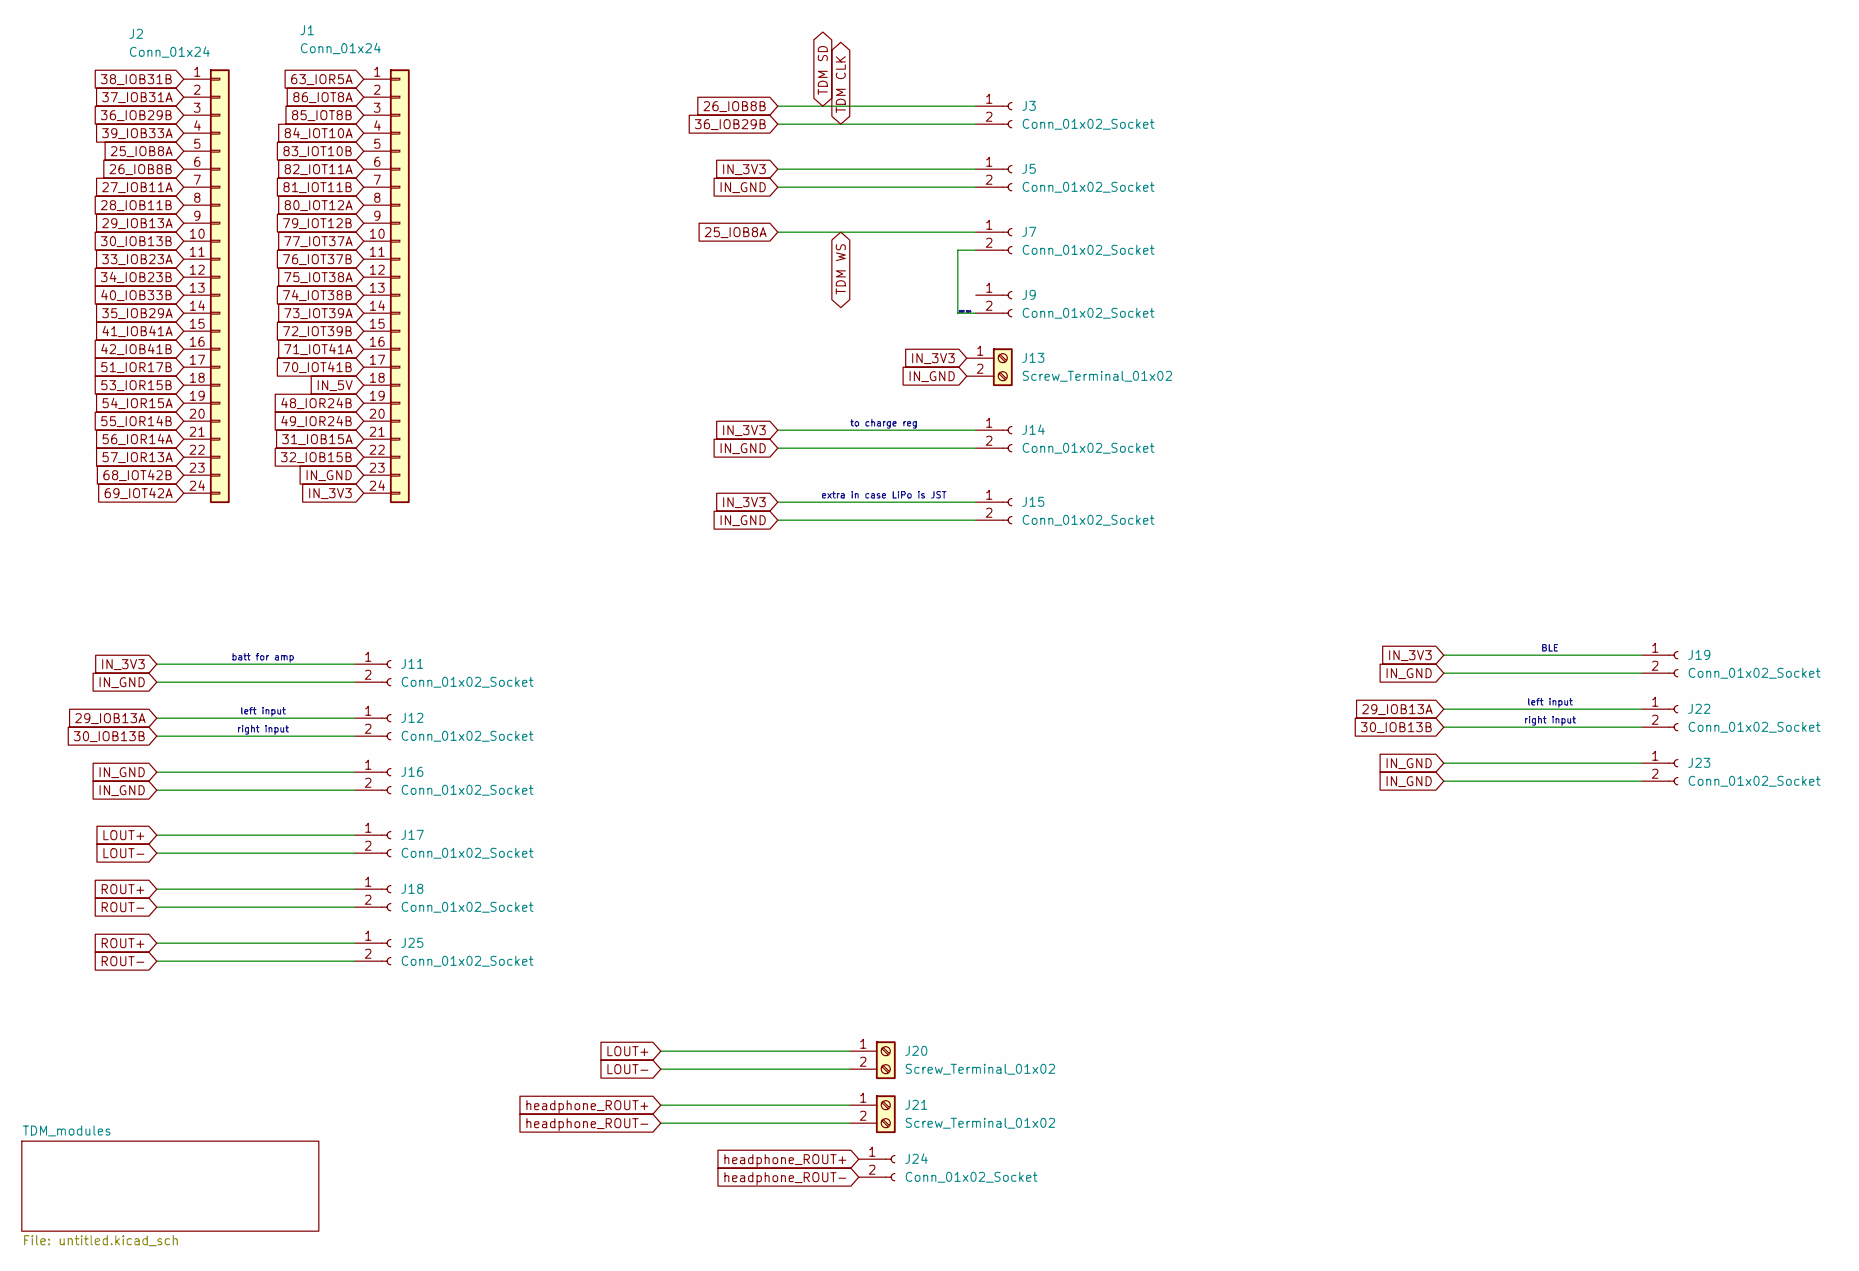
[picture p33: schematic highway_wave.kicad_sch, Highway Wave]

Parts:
J1, J2: Conn_01x24; PinSocket_1x24_P2.54mm_Vertical
J3, J5, J7, J9, J11, J12, J14, J15, J16, J17, J18, J19, J22, J23, J24, J25: Conn_01x02_Socket; JST_PH_B2B-PH-K_1x02_P2.00mm_Vertical
J13, J20, J21: Screw_Terminal_01x02; TerminalBlock_MetzConnect_Type101_RT01602HBWC_1x02_P5.08mm_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

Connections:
25_IOB8A: J2.5, J7.1
26_IOB8B: J2.6, J3.1; also elsewhere on the board
27_IOB11A: J2.7
28_IOB11B: J2.8
29_IOB13A: J2.9, J12.1, J22.1
30_IOB13B: J2.10, J12.2, J22.2
31_IOB15A: J1.21
32_IOB15B: J1.22
33_IOB23A: J2.11
34_IOB23B: J2.12
35_IOB29A: J2.14
36_IOB29B: J2.3, J3.2; also elsewhere on the board
37_IOB31A: J2.2
38_IOB31B: J2.1
39_IOB33A: J2.4
40_IOB33B: J2.13
41_IOB41A: J2.15
42_IOB41B: J2.16
48_IOR24B: J1.19
49_IOR24B: J1.20
51_IOR17B: J2.17
53_IOR15B: J2.18
54_IOR15A: J2.19
55_IOR14B: J2.20
56_IOR14A: J2.21
57_IOR13A: J2.22
63_IOR5A: J1.1
68_IOT42B: J2.23
69_IOT42A: J2.24
70_IOT41B: J1.17
71_IOT41A: J1.16
72_IOT39B: J1.15
73_IOT39A: J1.14
74_IOT38B: J1.13
75_IOT38A: J1.12
76_IOT37B: J1.11
77_IOT37A: J1.10
79_IOT12B: J1.9
80_IOT12A: J1.8
81_IOT11B: J1.7
82_IOT11A: J1.6
83_IOT10B: J1.5
84_IOT10A: J1.4
85_IOT8B: J1.3
86_IOT8A: J1.2
IN_3V3: J1.24, J5.1, J11.1, J13.1, J14.1, J15.1, J19.1; also elsewhere on the board
IN_5V: J1.18
IN_GND: J1.23, J5.2, J11.2, J13.2, J14.2, J15.2, J16.1, J16.2, J19.2, J23.1, J23.2; also elsewhere on the board
LOUT+: J17.1, J20.1
LOUT-: J17.2, J20.2
unnamed: J7.2, J9.2
ROUT+: J18.1, J25.1
ROUT-: J18.2, J25.2
headphone_ROUT+: J21.1, J24.1
headphone_ROUT-: J21.2, J24.2

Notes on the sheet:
BLE
extra in case LiPo is JST
right input
left input
batt for amp
to charge reg
WSO Mk4

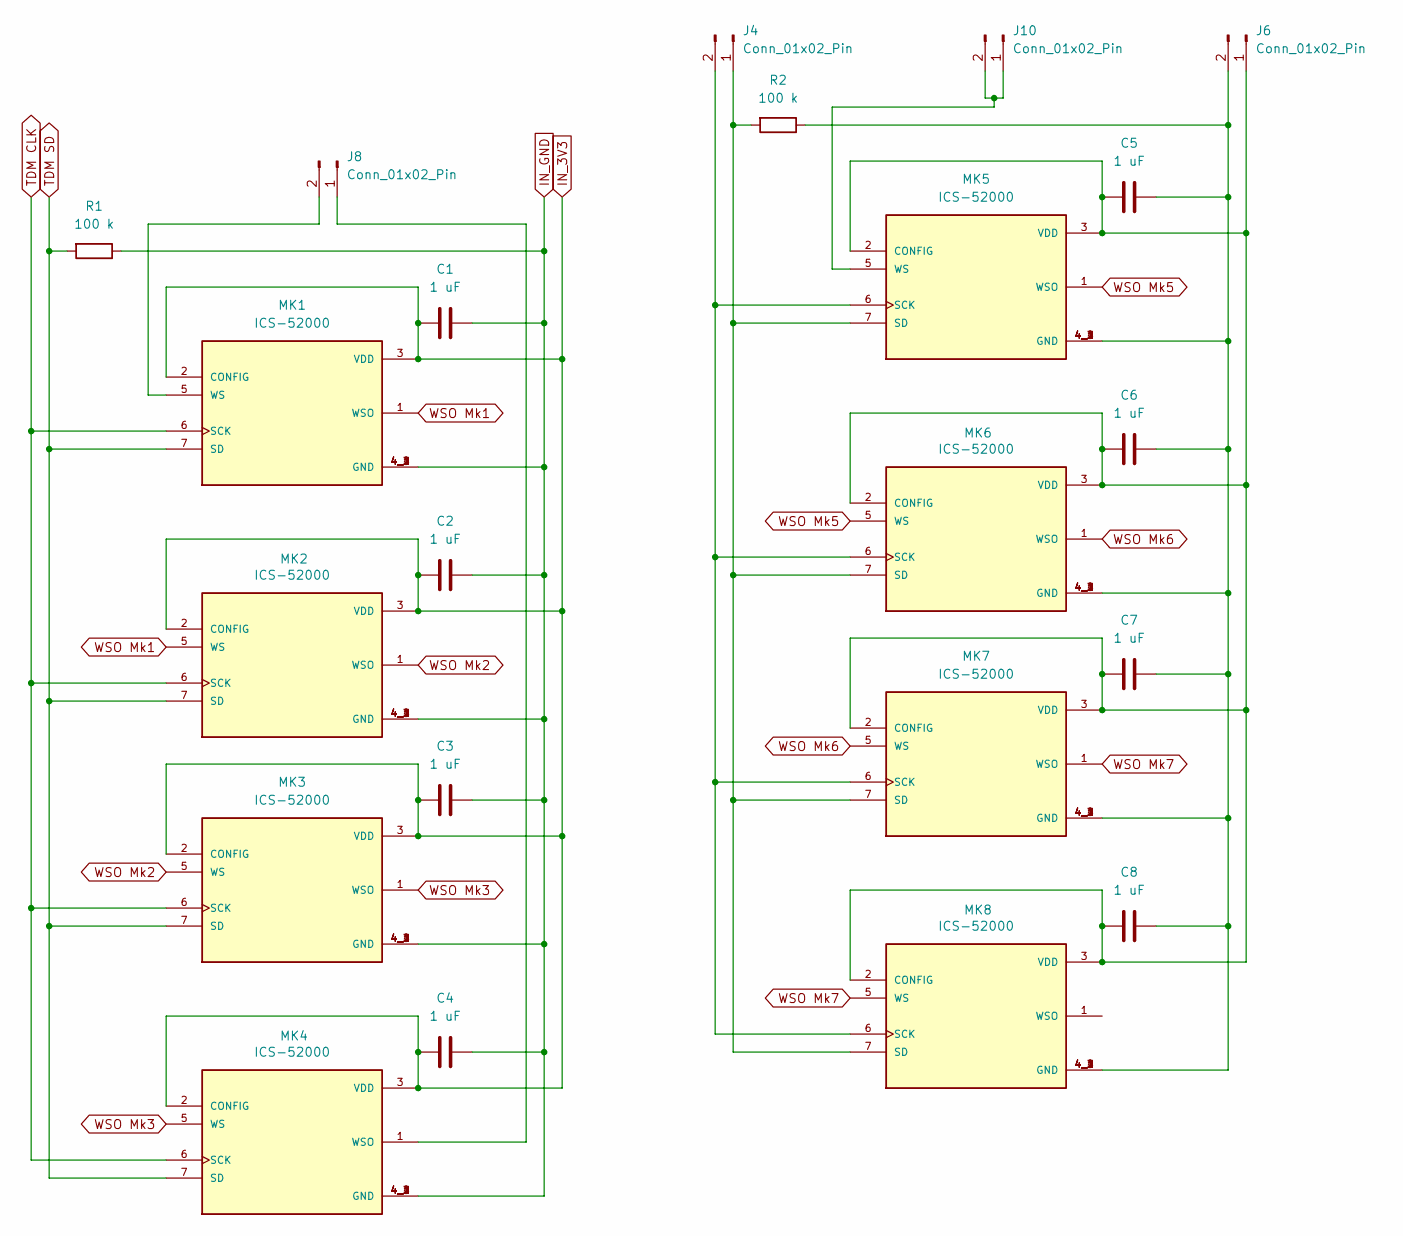
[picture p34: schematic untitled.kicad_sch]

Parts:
C1, C2, C3, C4, C5, C6, C7, C8: 1 uF; C_Disc_D5.0mm_W2.5mm_P5.00mm
J4, J6, J8, J10: Conn_01x02_Pin; JST_PH_B2B-PH-K_1x02_P2.00mm_Vertical
MK1, MK2, MK3, MK4, MK5, MK6, MK7, MK8: ICS-52000; MIC_ICS-52000; PARTREV 1.3
R1, R2: 100 k; R_Axial_DIN0207_L6.3mm_D2.5mm_P7.62mm_Horizontal

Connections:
26_IOB8B: MK1.7 (SD), MK2.7 (SD), MK3.7 (SD), MK4.7 (SD), R1.2; also elsewhere on the board
36_IOB29B: MK1.6 (SCK), MK2.6 (SCK), MK3.6 (SCK), MK4.6 (SCK); also elsewhere on the board
IN_3V3: C1.1, C2.1, C3.1, C4.1, MK1.2 (CONFIG), MK1.3 (VDD), MK2.2 (CONFIG), MK2.3 (VDD), MK3.2 (CONFIG), MK3.3 (VDD), MK4.2 (CONFIG), MK4.3 (VDD); also elsewhere on the board
IN_GND: C1.2, C2.2, C3.2, C4.2, MK1.4_1 (GND), MK1.4_2 (GND), MK1.4_3 (GND), MK1.4_4 (GND), MK2.4_1 (GND), MK2.4_2 (GND), MK2.4_3 (GND), MK2.4_4 (GND), MK3.4_1 (GND), MK3.4_2 (GND), MK3.4_3 (GND), MK3.4_4 (GND), MK4.4_1 (GND), MK4.4_2 (GND), MK4.4_3 (GND), MK4.4_4 (GND), R1.1; also elsewhere on the board
unnamed: J4.1, MK5.7 (SD), MK6.7 (SD), MK7.7 (SD), MK8.7 (SD), R2.2
unnamed: J4.2, MK5.6 (SCK), MK6.6 (SCK), MK7.6 (SCK), MK8.6 (SCK)
unnamed: C5.1, C6.1, C7.1, C8.1, J6.1, MK5.2 (CONFIG), MK5.3 (VDD), MK6.2 (CONFIG), MK6.3 (VDD), MK7.2 (CONFIG), MK7.3 (VDD), MK8.2 (CONFIG), MK8.3 (VDD)
unnamed: C5.2, C6.2, C7.2, C8.2, J6.2, MK5.4_1 (GND), MK5.4_2 (GND), MK5.4_3 (GND), MK5.4_4 (GND), MK6.4_1 (GND), MK6.4_2 (GND), MK6.4_3 (GND), MK6.4_4 (GND), MK7.4_1 (GND), MK7.4_2 (GND), MK7.4_3 (GND), MK7.4_4 (GND), MK8.4_1 (GND), MK8.4_2 (GND), MK8.4_3 (GND), MK8.4_4 (GND), R2.1
unnamed: J8.1, MK4.1 (WSO)
unnamed: J8.2, MK1.5 (WS)
unnamed: J10.1, J10.2, MK5.5 (WS)
WSO Mk1: MK1.1 (WSO), MK2.5 (WS)
WSO Mk2: MK2.1 (WSO), MK3.5 (WS)
WSO Mk3: MK3.1 (WSO), MK4.5 (WS)
WSO Mk5: MK5.1 (WSO), MK6.5 (WS)
WSO Mk6: MK6.1 (WSO), MK7.5 (WS)
WSO Mk7: MK7.1 (WSO), MK8.5 (WS)

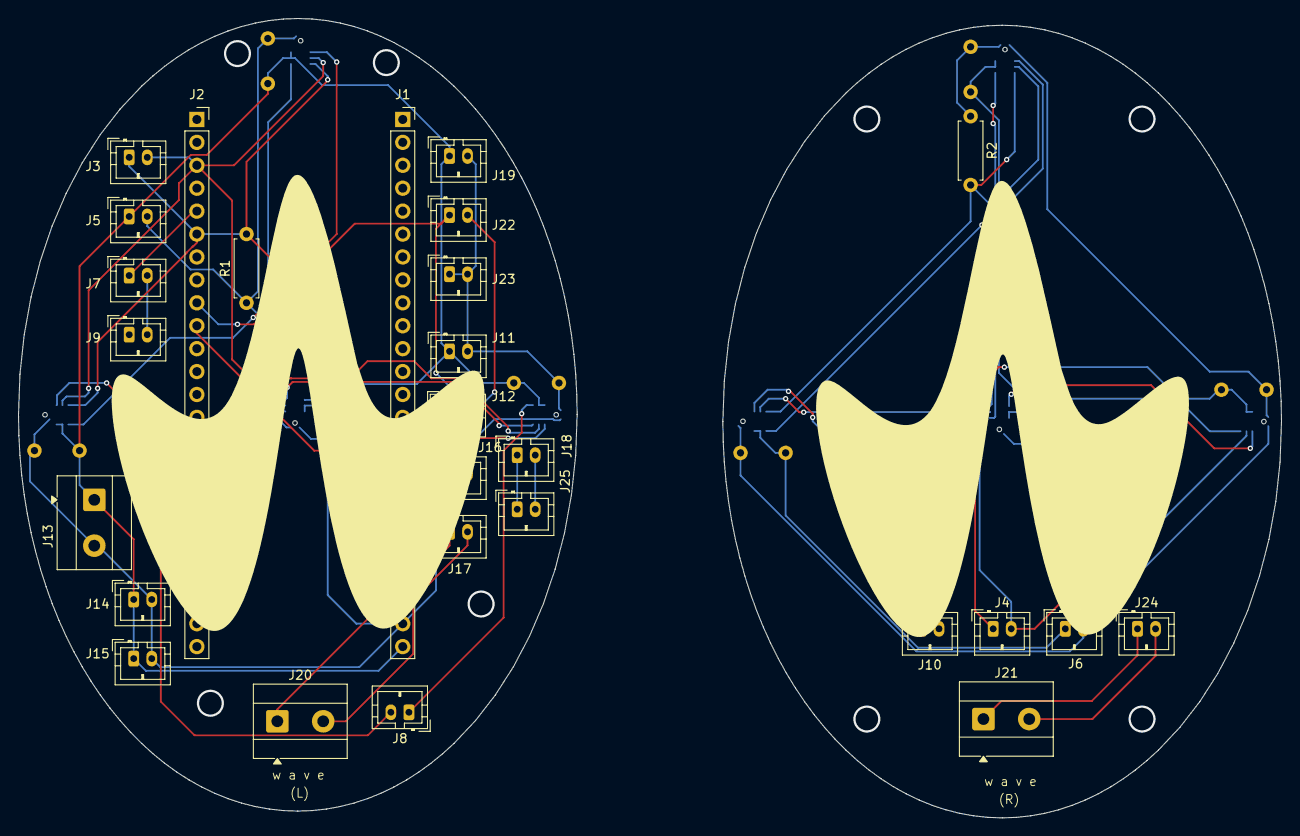
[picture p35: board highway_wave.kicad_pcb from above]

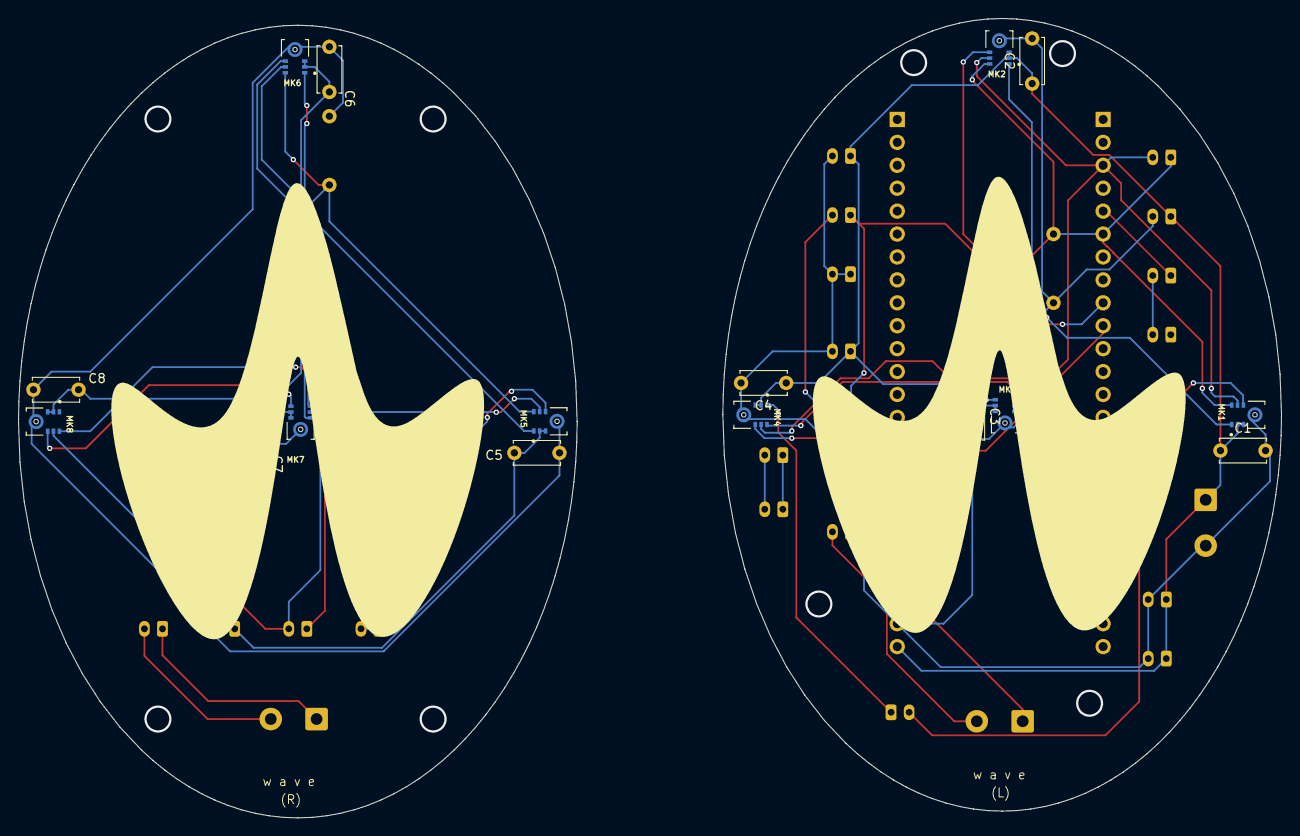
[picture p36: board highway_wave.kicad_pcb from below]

Board: 2 copper layers, 140.0 x 88.6 mm, 43 parts (16 on the bottom side), 27 nets.

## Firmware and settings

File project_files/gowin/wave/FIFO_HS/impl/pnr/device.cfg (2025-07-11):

set JTAG regular_io = false
set SSPI regular_io = false
set MSPI regular_io = false
set READY regular_io = false
set DONE regular_io = false
set I2C regular_io = false
set RECONFIG_N regular_io = false
set unused_pin = default
set CRC_check = true
set compress = false
set encryption = false
set security_bit_enable = true
set bsram_init_fuse_print = true
set background_programming = off
set secure_mode = false
set program_done_bypass = false
set wake_up = 0
set format = binary
set power_on_reset_monitor = true
set multiboot_spi_flash_address = 0x00000000
set vccx = 3.3
set vcc = 1.2

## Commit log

2025-05-23 basic idea nothing conrete yet
    [BOM.csv, BOM.xlsx]
2025-06-14 cad & readme
    [highway_wave.step]
2025-06-14 added schematic
    [RASPBERRY_PI_PICO.step, highway_wave.kicad_pcb, highway_wave.kicad_sch]
2025-06-15 Added FPGA to parts list and correct driver
    [BOM.xlsx, GW1N-LV9QN88C6_I5_.step, highway_wave.kicad_sch]
2025-06-20 finished schem
    [BOM.xlsx, INMP441ACEZ-R7.step, highway_wave.kicad_sch]
2025-06-20 exported schem
    [highway_wave.kicad_sch]
2025-06-20 final updated README
    [BOM.csv, BOM.xlsx, highway_wave.step]
2025-06-23 ESP32-S3 direction
    [highway_wave.kicad_pcb, highway_wave.kicad_sch]
2025-06-26 big updates to pcb
    [ICS-43432.step, ICS-52000.step, MOUDLE-BLUETOOTH-AUDIO-BC127_51P-18X11.8MM_.step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]
2025-06-28 random committ
    [highway_wave.kicad_pcb, highway_wave.kicad_sch, untitled.kicad_sch]
2025-07-11 fixed pcb
    [bom.csv, designators.csv, device.cfg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]
2025-07-11 journal updates
    [highway_wave.kicad_pcb, highway_wave.step]
2025-07-11 ok final?
    [BOM.csv, BOM.xlsx]
2025-07-11 new step file
    [highway_wave.step]
2025-07-16 Updated BOM and ReadMe
2025-07-16 oops forgot to save the xlsx
    [BOM.xlsx]
2025-07-28 moved caps on PCB
    [highway_wave.kicad_pcb, positions.csv]
2025-08-03 update BOM
    [BOM.xlsx, bom.csv, designators.csv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]
2025-08-03 update csv
    [BOM.csv]
